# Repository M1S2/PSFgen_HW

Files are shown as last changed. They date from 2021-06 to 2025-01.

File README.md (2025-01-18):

# PS_Fgen_HW
Hardware for an PowerSupply and Functiongenerator build from an ATX power supply.

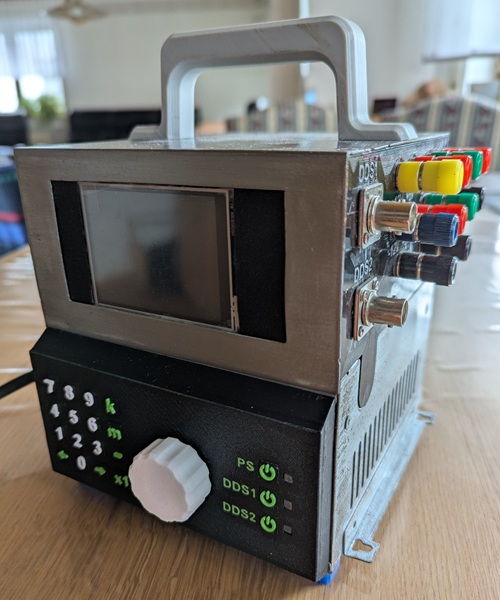
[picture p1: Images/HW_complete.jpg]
PS_Fgen_HW


## ATX Supply
The hardware of the power supply and function generator is based on the following ATX supply:
``Yuan Kee 230P ATX``

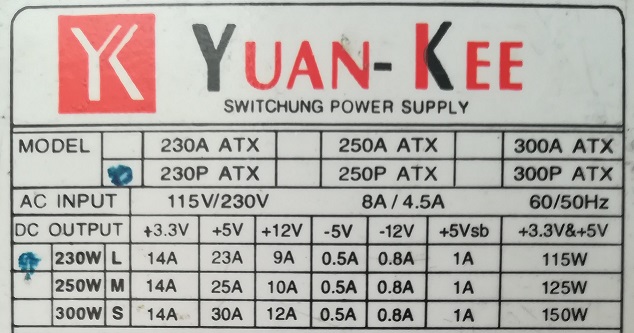
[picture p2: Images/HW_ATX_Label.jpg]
ATX


By using another ATX supply, some output capabilities can be changed / enhanced.

## Input / Output Capabilities

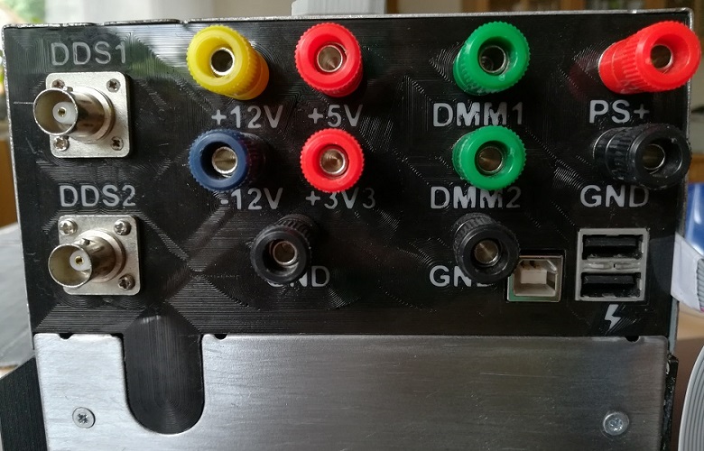
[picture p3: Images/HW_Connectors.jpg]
Connectors


The power supply and function generator features the following capabilites:

### Power Supply output (PS+)
One power supply output is available.
Connector		| PS+
-----------------------	| -----------------
Voltage			| 0 .. 10 V DC
Current			| 0 .. 2 A
Protections		| OVP, OCP, OPP

The voltage and current regulation is done in firmware.
The protections are implemented in firmware, too.

### DDS outputs (DDS1, DDS2)
Two direct digital synthesis outputs are available.
Connector		| DDS1						| DDS2
-----------------------	| ---------------------------------------------	| ---------------------------------------------
Amplitude		| 0 .. 20 Vpp					| 0 .. 20 Vpp
Offset			| -10 V .. 10 V					| -10 V .. 10 V
Frequency		| approx. max. 170 kHz				| approx. max. 170 kHz
Waveforms		| FW defined (Sine, Square, Triangle, ...)	| FW defined (Sine, Square, Triangle, ...)

The waveforms are defined in firmware. Default waveforms like sine, square and triangle are supported. By using DDS it is possible to even generate user defined waveforms.
The maximum frequency is limited by the low pass filter after the DAC outputs. The cutoff frequency is approximately 170 kHz. The real frequency range depends on the DDS implementation in the firmware!

### DMM inputs (DMM1, DMM2)
Two digital multimeter inputs are available.
Connector	| DMM1		| DMM2
---------------	| -------------	| ---------------
Input Range	| 0 .. 20 V DC	| 0 .. 20 V DC

Negative voltages on the DMM inputs between -20 V and 0 V are allowed but the output is clipped to 0 V!
The measured voltage for negative inputs is 0 V and a warning signal is generated.

### USB outputs
Two USB outputs are available. They are connected to the 5V output of the ATX supply. So the combined current capability for both USB ports are 23 A.

### USB input
The USB input can be used to communicate to the device via serial port.

### ATX outputs
All output voltages of the ATX supply are directly available through connectors on the connector panel. The currents are directly depending on the used ATX supply (values for the Yuan Kee 230P ATX).
Connector		| +5V	| +3V3	| +12V	| -12V
-----------------------	| -----	| -----	| -----	| -----
Voltage			| 5 V	| 3,3 V	| 12 V	| -12 V
Current (max.)		| 23 A	| 14 A	| 9 A	| 0.8 A

## User Interface

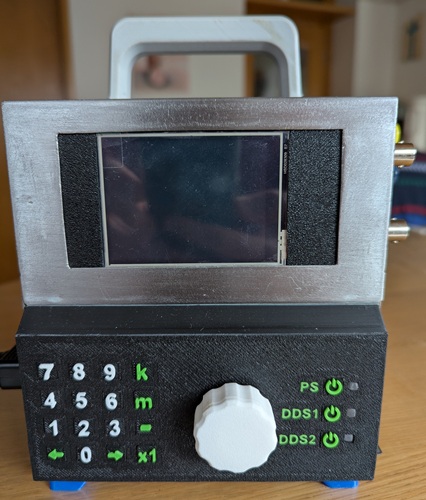
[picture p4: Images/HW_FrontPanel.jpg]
FrontPanel


The user interface is made up of the following components:
- Graphical display: A 320x240 pixel graphical LCD is used to display the device status and current settings.
- Encoder: A rotary encoder can be used for value editing and menu navigation.
- KeyPad: A 16 button keypad can be used for value editing and menu navigation.
- OnOffControls: A PCB with buttons and LEDs for faster enabling of the channels and status display.

The user interface logic is defined by the firmware.

## Electronic
The electronic is divided into the following PCBs:
- **FrontPanel:** The front panel is containing 16 push buttons forming a 4x4 keypad and a rotary encoder for user input. It is connected to the MainBoard using a ribbon cable.
- **MainBoard:** The main board is containing all other components that can be grouped like following:
	- *Microcontroller*: The main controller of the power supply and function generator. It controls everything from user input handling to output generation. The used type is an ATmega1284P.
	- *Serial communication:* A FT232RL USB-UART IC is used for serial communication to the microcontroller via USB.
	- *GLCD:* The used graphic LCD model is ``ILI9341``. It has 320x240 pixels and is controllable via SPI. **Important:** The display uses a 3.3 V logic level!
	- *ATX voltage monitors:* The ATX 5 V and 3.3 V lines are each directly connected to ADCs of the microcontroller. The 12V and -12V lines aren't monitored anymore because the input pins were needed for other purposes.
	- *DMM inputs:* The two DMM inputs can be used to measure positive input voltages. The resistor divider scales the input voltage so that the maximum DMM input voltage equals 5 V (maximum allowed voltage of the microcontroller ADC inputs).  **Important:** Voltages higher than the maximum DMM input voltage can damage the inputs.
	- *DDS outputs:* The two DDS output signals are generated by a dual output DAC IC (MCP4921, output 0..5 V for each output) followed by an offset and amplification stage (used to create a range of -10 V .. 10 V). The output is buffered by an OpAmp and two transistors for higher currents.
	- *PS output:* The PS output signal is generated by a single output DAC IC (MCP4921, output 0..5 V) and buffered by an OpAmp and two transistors for higher currents. The voltage at the PS output is measured by a simple resistor voltage divider. The current at the PS output is measured by transforming it into a voltage proportional to the current.
- **DMMRectifier:** The DMMRectifier is used to protect the ADC DMM inputs from negative inputs on the DMM1 and DMM2 connectors. Negative voltages are clipped to 0 V and a warning signal is generated when the voltage on the inputs are negative.
- **OnOffControls:** The OnOffControls are buttons and LEDs for faster enabling of the channels and status display.

The FrontPanel, DMMRectifier and OnOffControls PCBs were designed to be manufactured with toner transfer method.

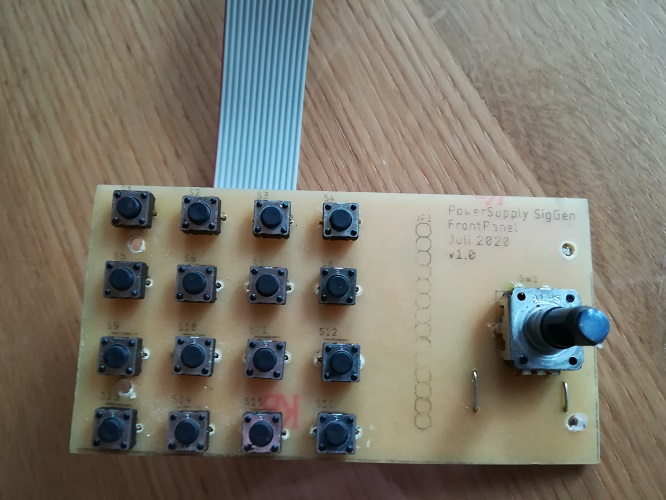
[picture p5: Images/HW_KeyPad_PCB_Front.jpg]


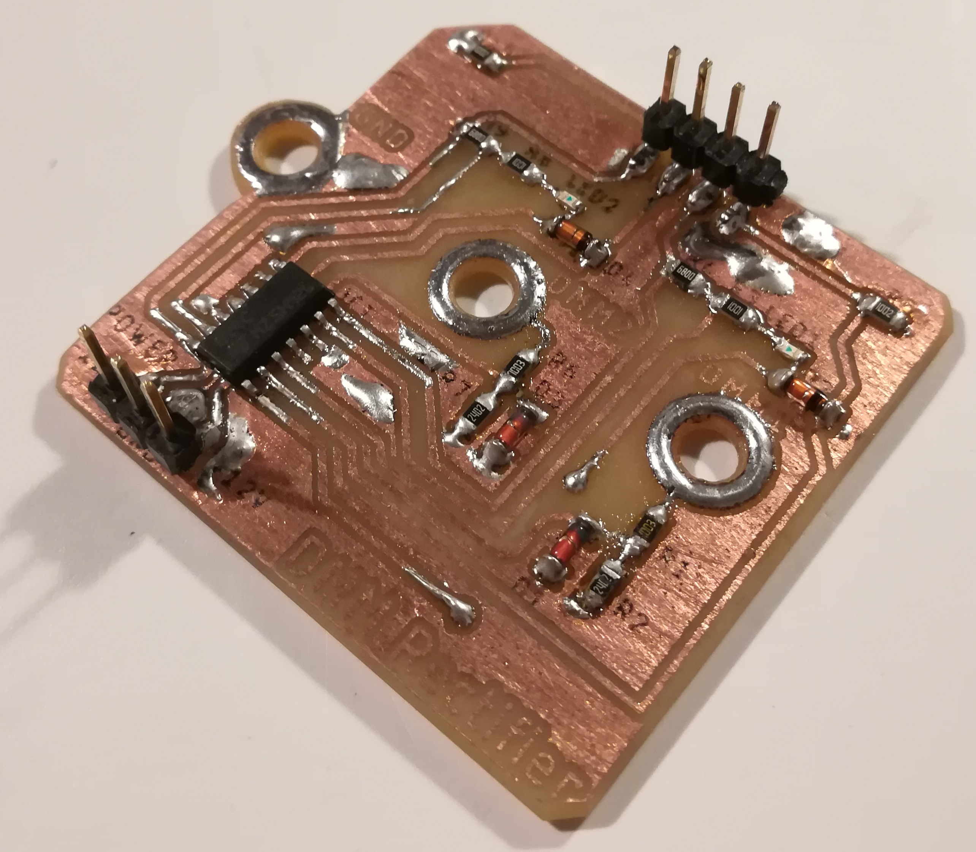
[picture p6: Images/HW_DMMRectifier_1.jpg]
DMMRectifier


The MainBoard PCB was too complex for manual manufacturing and was therefore made by JLCPCB.

!!! :warning: Caution: The MainBoard was designed to a size of 100 x 100 mm to fit the maximum size of JLCPCB. Eagle changed the maximum board size to 100 x 80 mm in 2022. Therefore the board can't be modified anymore. But the schematics are up-to-date. !!! 

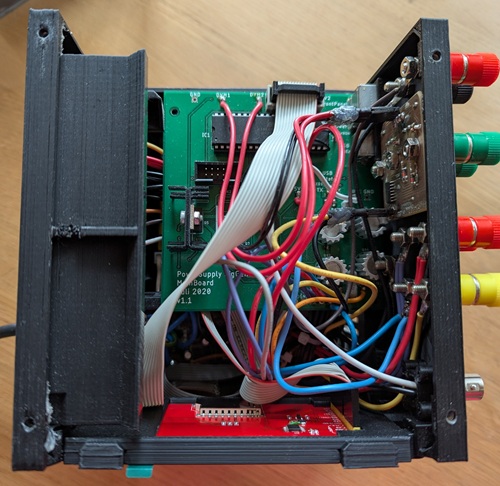
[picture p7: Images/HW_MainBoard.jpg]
MainBoard


## Housing
All housing components are made for the above ATX supply and are not guaranteed to fit for any other ATX supply. Nevertheless all construction files are available in the Mechanical folder and can be adapted, if neccessary.
The parts were designed using Autodesk Fusion 360 (.f3d files) and are exported as .stl files.
The .stl files were used to 3D print all components.
All parts are needed once, except the `Standfuss.stl` (needed 4x).

## Firmware
The firmware for this power supply and function generator is developed in another repository:
[GitHub - M1S2/PS_Fgen_FW: Firmware for an Power Supply and Function Generator build from an ATX power supply](https://github.com/M1S2/PS_Fgen_FW)

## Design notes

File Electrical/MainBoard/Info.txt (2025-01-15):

No gerber or other output files because the PCB isn't really up to date (and it won't be anymore).
This is because of the new limitations of Fusion360 to a board size of 80x80 (previous was 100x100). The board must be completely redesigned.

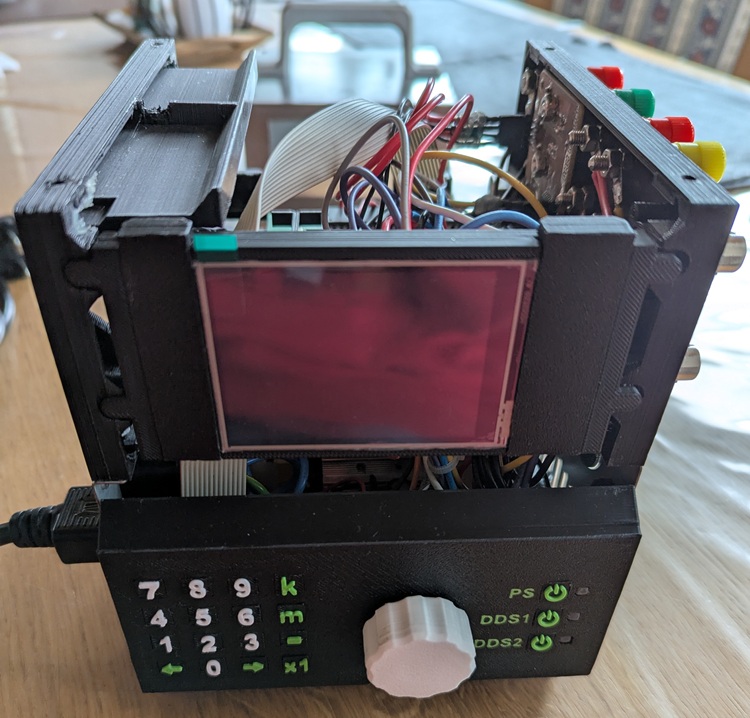
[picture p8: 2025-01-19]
Images/HW_WithoutCover.jpg

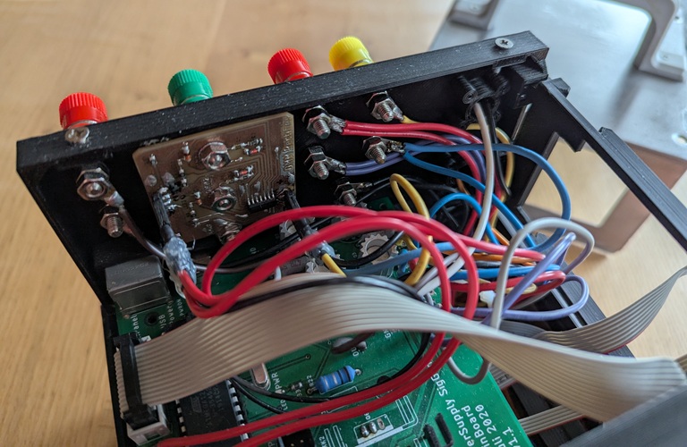
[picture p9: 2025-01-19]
Images/HW_Connectors_connection.jpg

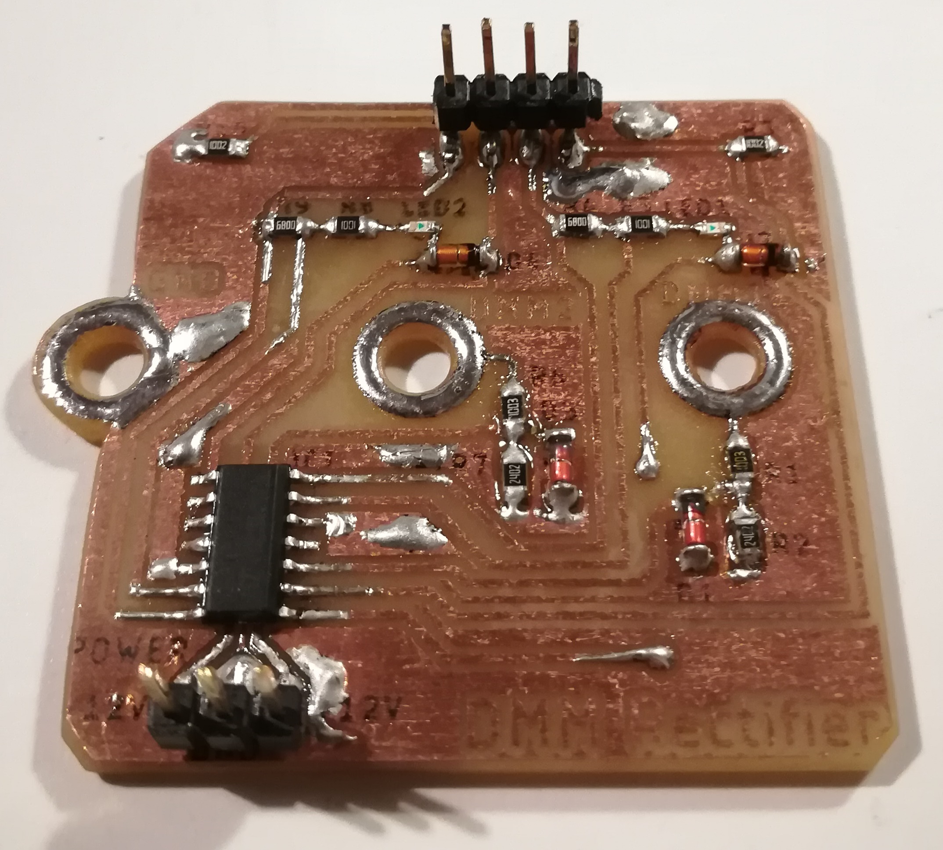
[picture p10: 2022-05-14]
Images/HW_DMMRectifier_3.jpg

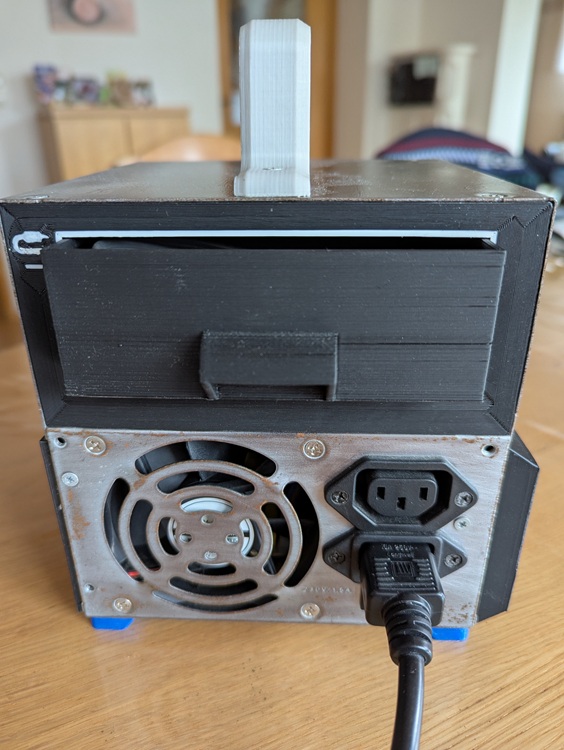
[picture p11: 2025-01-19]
Images/HW_Side.jpg

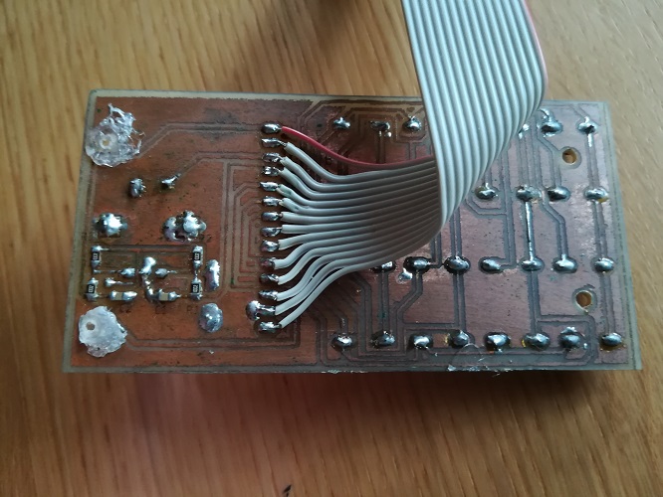
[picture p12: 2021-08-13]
Images/HW_KeyPad_PCB_Back.jpg

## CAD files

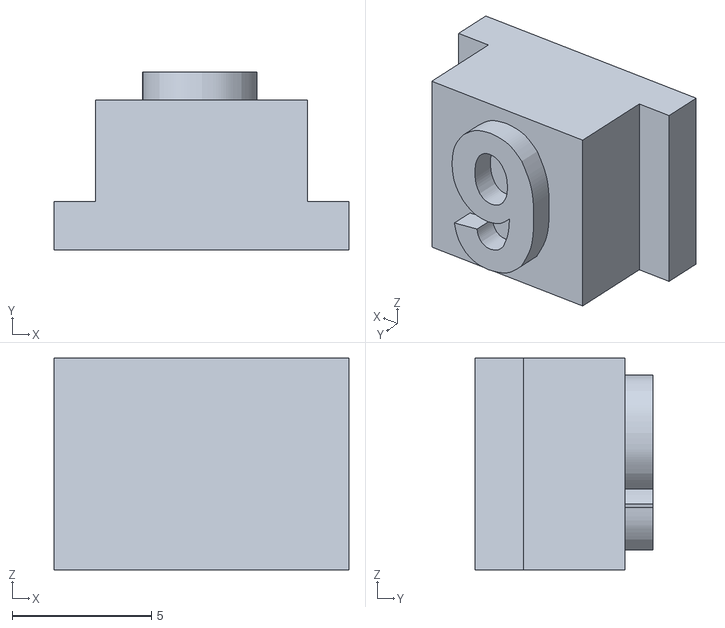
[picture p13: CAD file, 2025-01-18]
Mechanical/Taste9_v56.stl
10.6 x 6.40 x 7.60

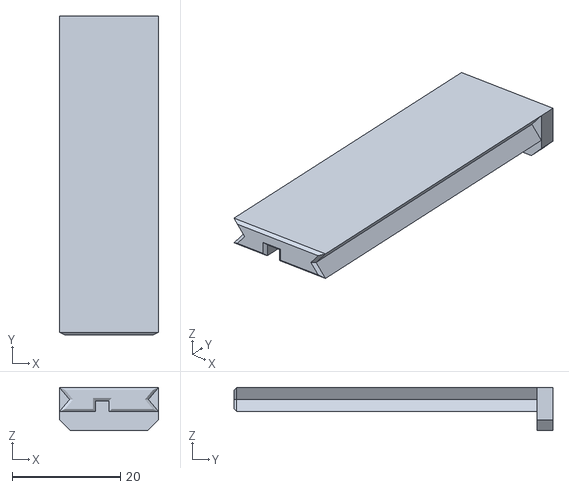
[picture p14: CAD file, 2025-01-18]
Mechanical/TFT_Holder_2_v4.stl
18.4 x 59.0 x 8.00

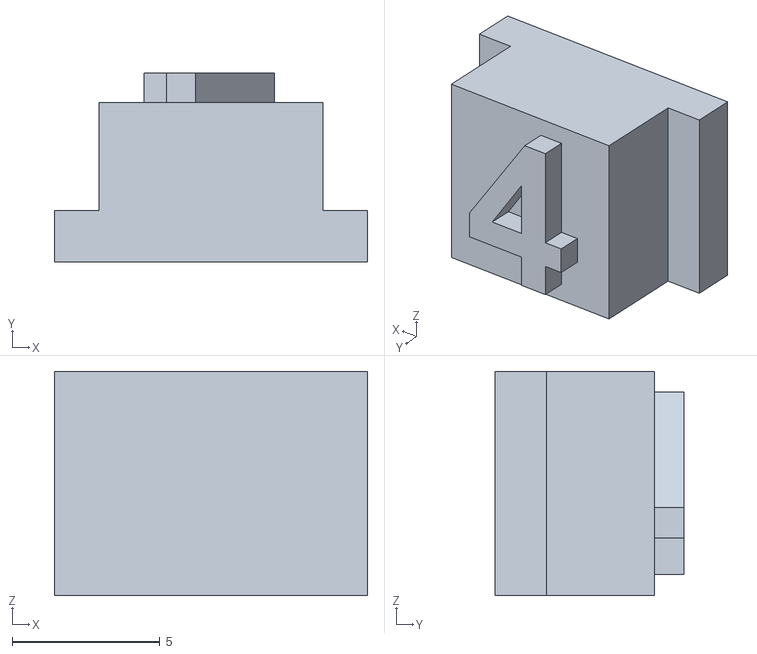
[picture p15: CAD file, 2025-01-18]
Mechanical/Taste4_v56.stl
10.6 x 6.40 x 7.60

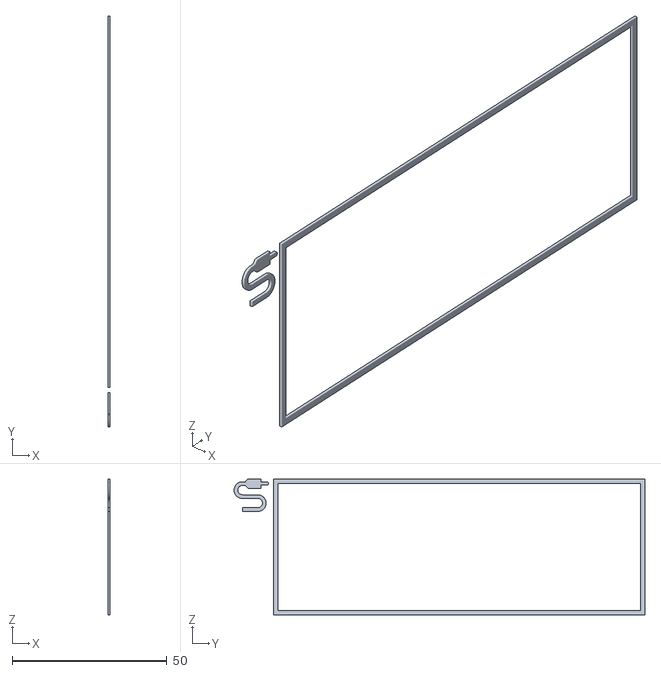
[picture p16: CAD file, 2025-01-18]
Mechanical/Schrift_Seitenteil_links_v56.stl
0.6 x 133.0 x 44.0

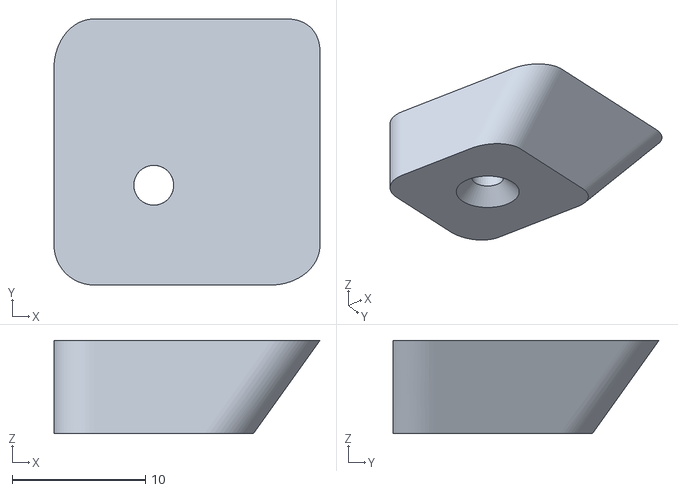
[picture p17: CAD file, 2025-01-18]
Mechanical/Standfuss_v56.stl
20.0 x 20.0 x 7.00

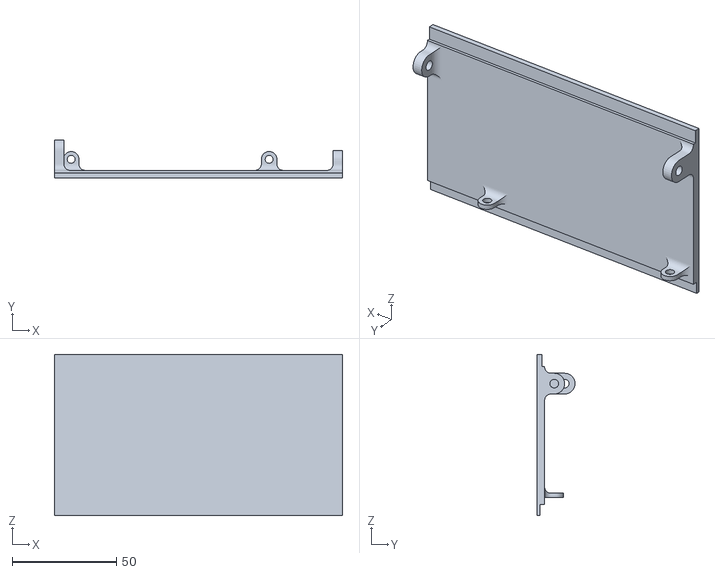
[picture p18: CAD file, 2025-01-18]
Mechanical/Abdeckung_hinten_v56.stl
138.2 x 18.3 x 77.3

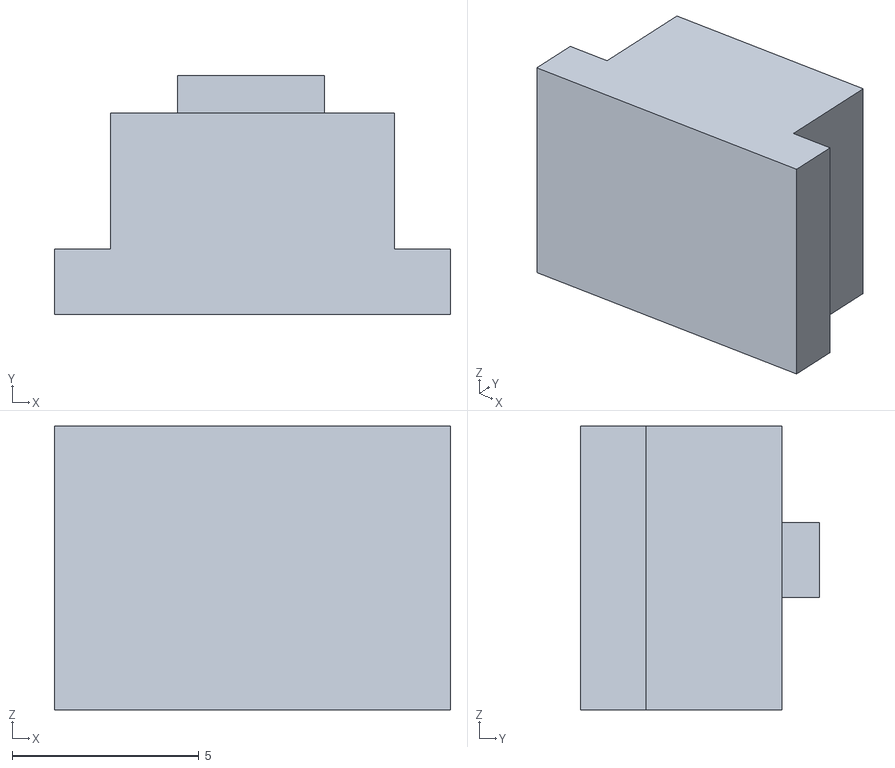
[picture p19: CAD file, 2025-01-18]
Mechanical/Taste_minus_v56.stl
10.6 x 6.40 x 7.60

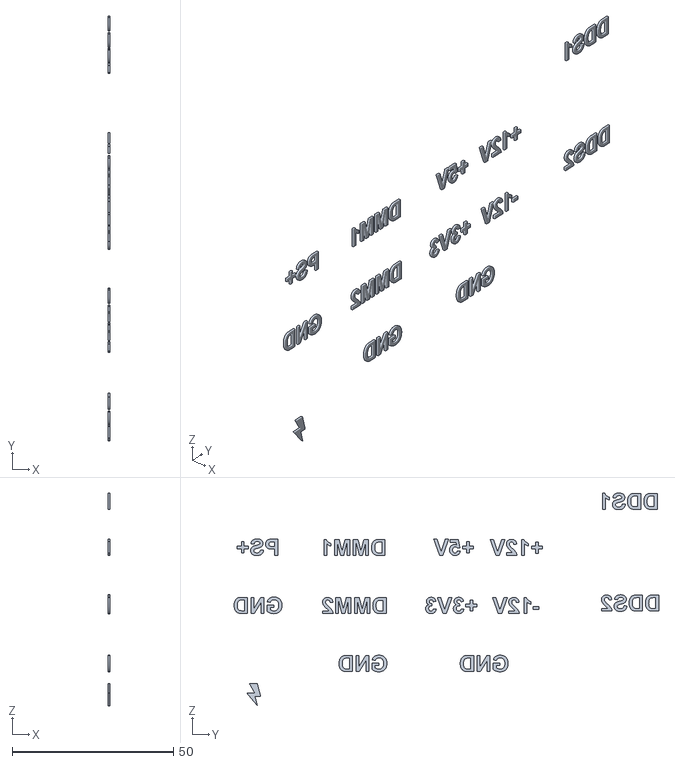
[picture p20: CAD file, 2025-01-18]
Mechanical/Schrift_Seitenteil_rechts_v56.stl
0.5 x 131.6 x 66.0

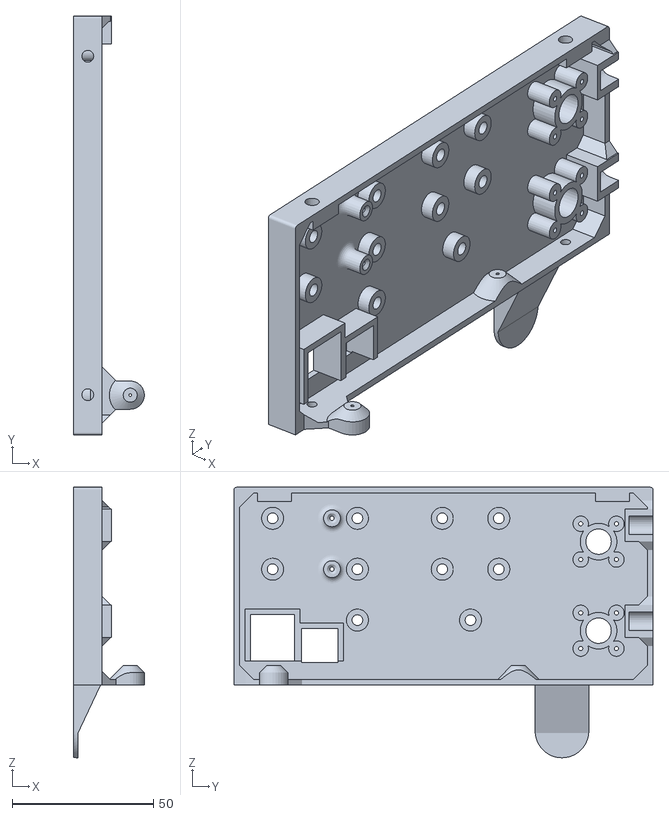
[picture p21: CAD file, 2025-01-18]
Mechanical/Seitenteil_rechts_v56.stl
25.0 x 148.2 x 95.7

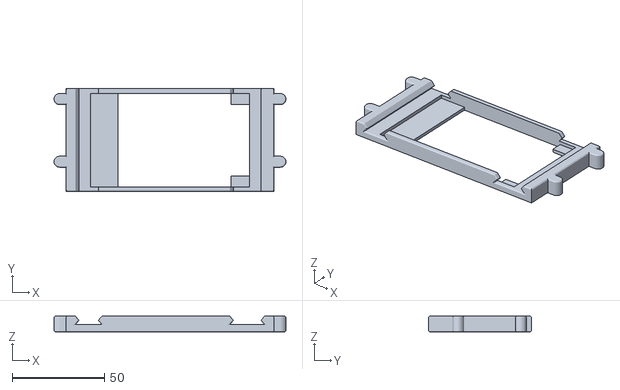
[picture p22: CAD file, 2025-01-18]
Mechanical/TFT_Adapter_v4.stl
125.9 x 56.0 x 8.44

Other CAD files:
Mechanical/Taste8_v56.stl
Mechanical/Taste_x1_v56.stl
Mechanical/Taste2_v56.stl
Mechanical/Taste5_v56.stl
Mechanical/Taste_links_v56.stl
Mechanical/Taste_k_v56.stl
Mechanical/Taste_rechts_v56.stl
Mechanical/Taste7_v56.stl
Mechanical/Abdeckung_hinten_v56.f3d
Mechanical/Encoder_Knopf_v56.f3d
Mechanical/Encoder_Knopf_v56.stl
Mechanical/FrontPanel_Rahmen_Schrift_v56.stl
Mechanical/FrontPanel_Rahmen_v56.f3d
Mechanical/FrontPanel_Rahmen_v56.stl
Mechanical/Griff_v56.f3d
Mechanical/Griff_v56.stl
Mechanical/Schrift_Seitenteil_links_v56.f3d
Mechanical/Schrift_Seitenteil_rechts_v56.f3d
Mechanical/Seitenteil_links_Schublade_v56.f3d
Mechanical/Seitenteil_links_Schublade_v56.stl
Mechanical/Seitenteil_links_v56.f3d
Mechanical/Seitenteil_links_v56.stl
Mechanical/Seitenteil_rechts_v56.f3d
Mechanical/Standfuss_v56.f3d
Mechanical/TFT_Holder_1_v4.stl
Mechanical/Taste0_v56.f3d
Mechanical/Taste0_v56.stl
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

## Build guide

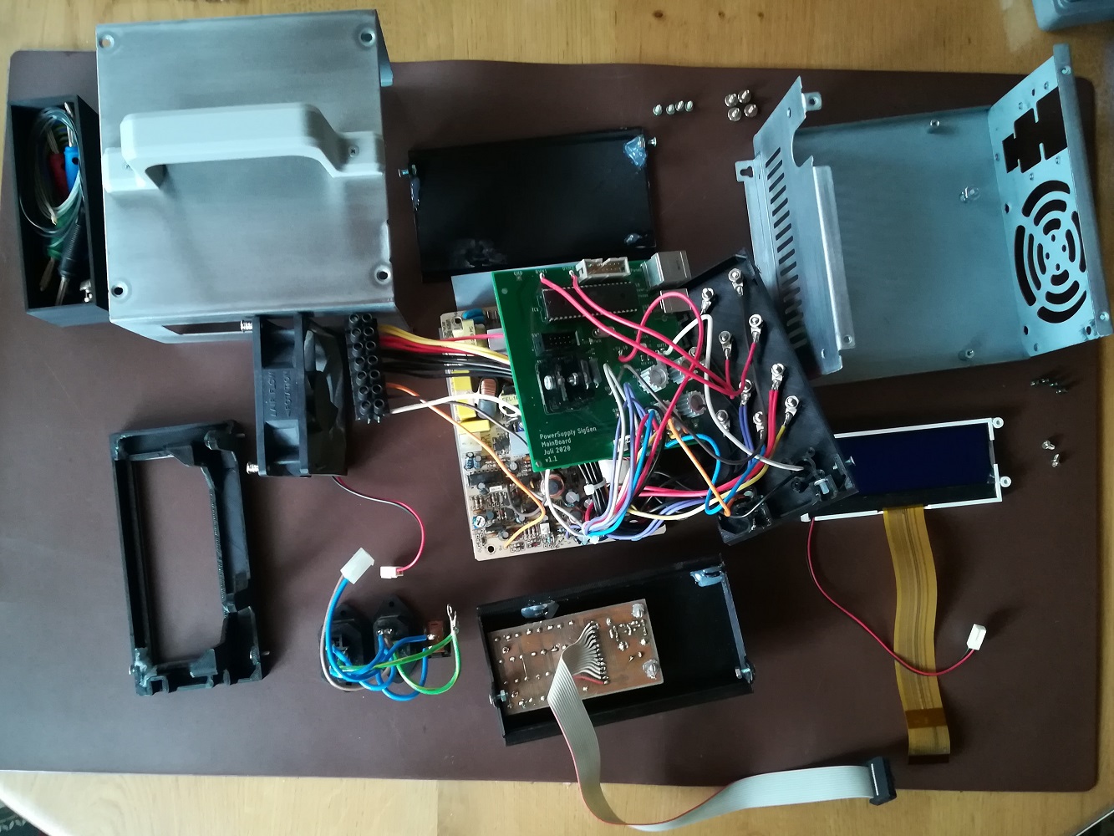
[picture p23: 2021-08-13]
Images/HW_Assembly1.jpg

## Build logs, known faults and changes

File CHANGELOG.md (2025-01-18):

# PS_Fgen_HW

## [%version%] - %date%

> Electrical > FrontPanel
- Nothing changed (equal to v1.1)
- Updated to new project name (PS_Fgen_HW)

> Electrical > MainBoard
- Resistors added to convert 5V to 3.3V for LCD signals (A0, CS, MOSI, SCK)
- Updated to new project name (PS_Fgen_HW)
- Removed some Z-Diodes
- Removed ATX_PWR_ON signal
- Removed ATX_5V_SB input (combined VCC and +5V nets)
- Removed resistor R20 (PowerSupply, between OpAmp IC5B and transistors Q5 and Q6)
- Changed resistor values of PowerSupply current measurement circuit (R21, R22, R23)
- Moved resistor R21 of current measurement circuit to be after this circuit
- Changed power stage of PowerSupply channel
- Modified DMM circuit to use DMMRectifier PCB
- ...

> Electrical > DMMRectifier
- Initial version of DMM Rectifier with simulation

> Mechanical
- Added Standfuss parts
- Modified Seitenteil_rechts for DMMRectifier
- ...

## [v1.1] - 07.08.2020
> Electrical > FrontPanel
- Nothing changed (equal to v1.0)

> Electrical > MainBoard
- Board size decreased to 100x100 to fit JLCPCB requirements for cheapter price
- Schematic not changed

> Mechanical
- Nothing changed (equal to v1.0)

## [v1.0] - 05.08.2020
> Electrical > FrontPanel
- Initial version

> Electrical > MainBoard
- Initial version

> Mechanical
- Initial version

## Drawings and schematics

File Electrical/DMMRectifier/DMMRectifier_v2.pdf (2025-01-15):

A

A

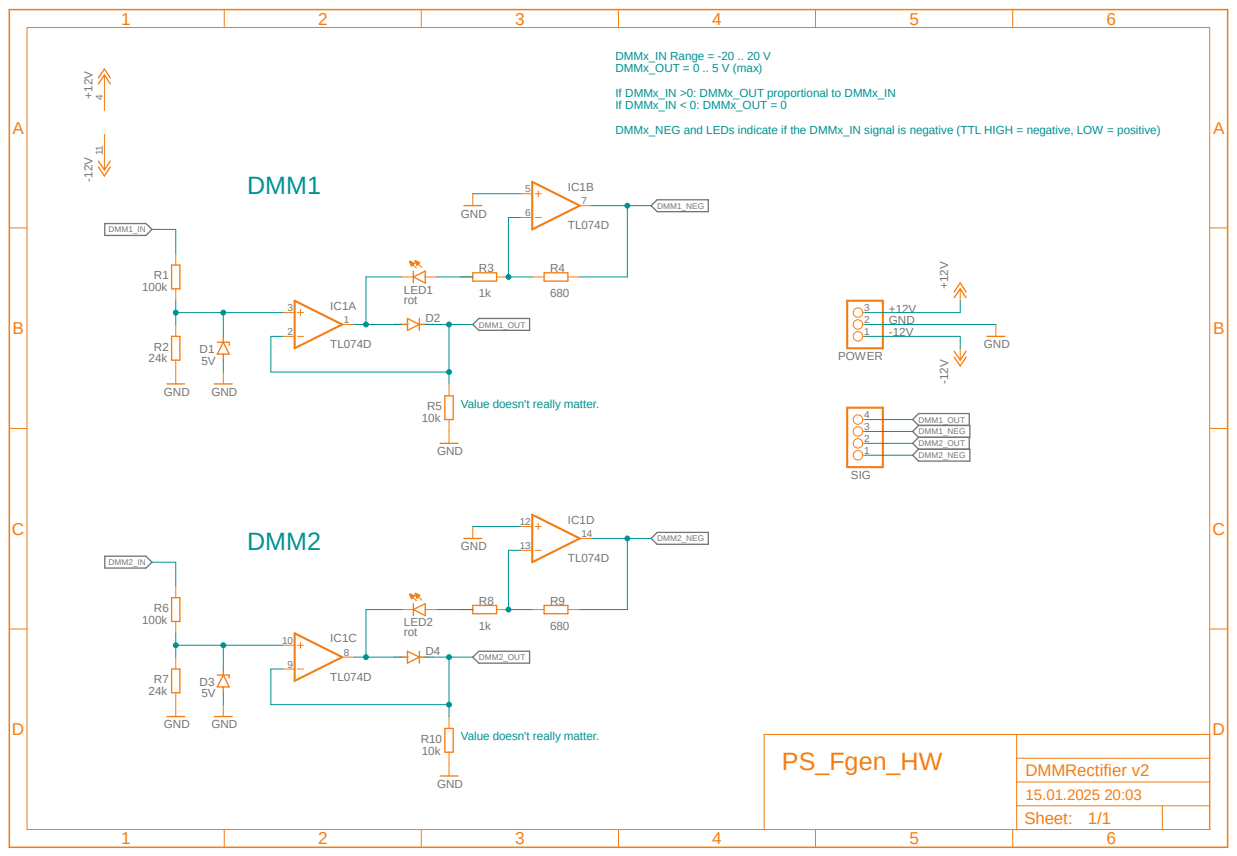
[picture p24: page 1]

DMMx_IN Range = -20 .. 20 V
DMMx_OUT = 0 .. 5 V (max)
If DMMx_IN >0: DMMx_OUT proportional to DMMx_IN
If DMMx_IN < 0: DMMx_OUT = 0
DMMx_NEG and LEDs indicate if the DMMx_IN signal is negative (TTL HIGH = negative, LOW = positive)

Value doesn't really matter.

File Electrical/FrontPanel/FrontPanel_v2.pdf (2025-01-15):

# Encoder +5V

# KEY_C1 KEY_C²

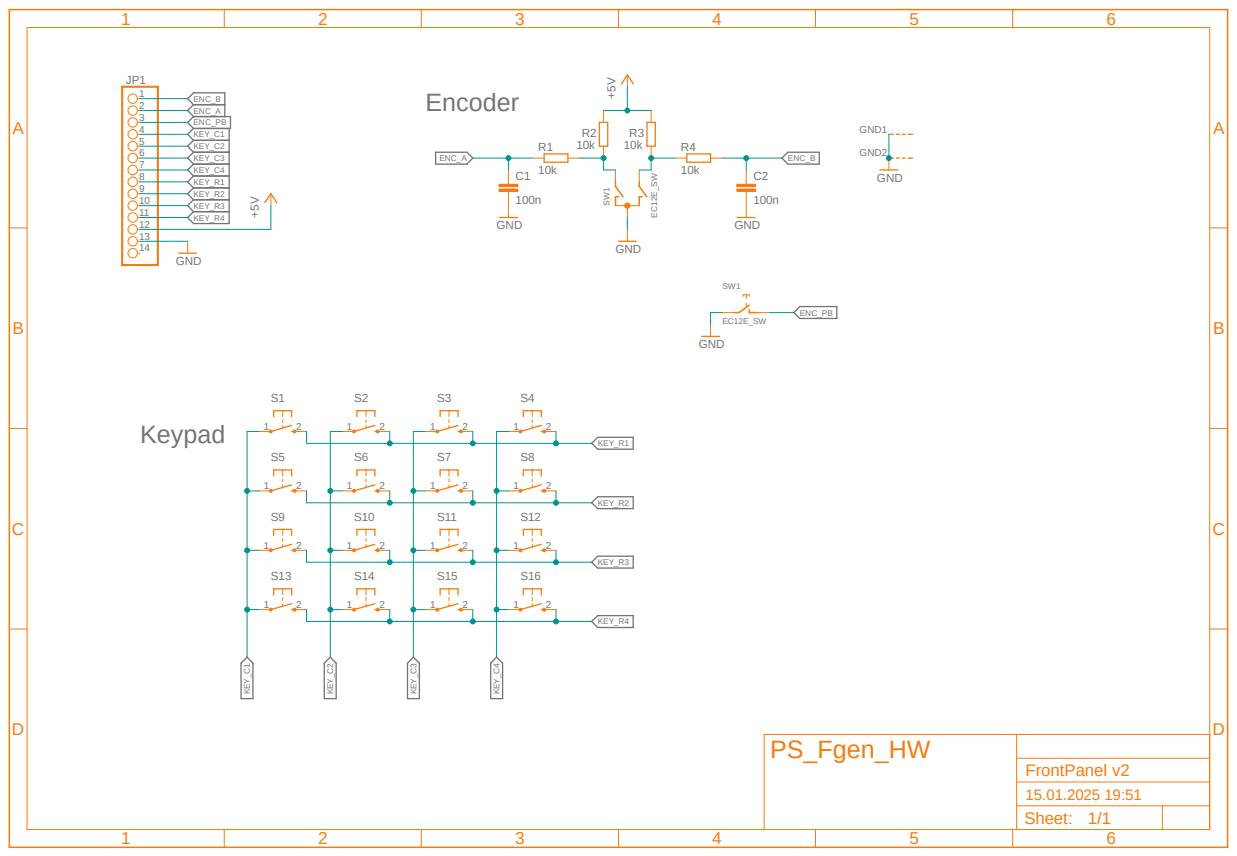
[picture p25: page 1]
Keypad; GND; EC¹²E_SW; GND ⁺⁵VJP1 1 2 3 4 5 6 7 8 9 10 11 12 13; 14 SW¹; GND1; GND2; C2 KEY_C¹; KEY_C2; KEY_C³; KEY_C3; KEY_C⁴; KEY_C4; KEY_R1; KEY_R2; KEY_R3; KEY_R4; ENC_PB; ENC_B; ENC_A; FrontPanel v2

PS_Fgen_HW

Sheet: 1/1

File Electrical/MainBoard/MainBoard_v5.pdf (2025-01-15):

A

A

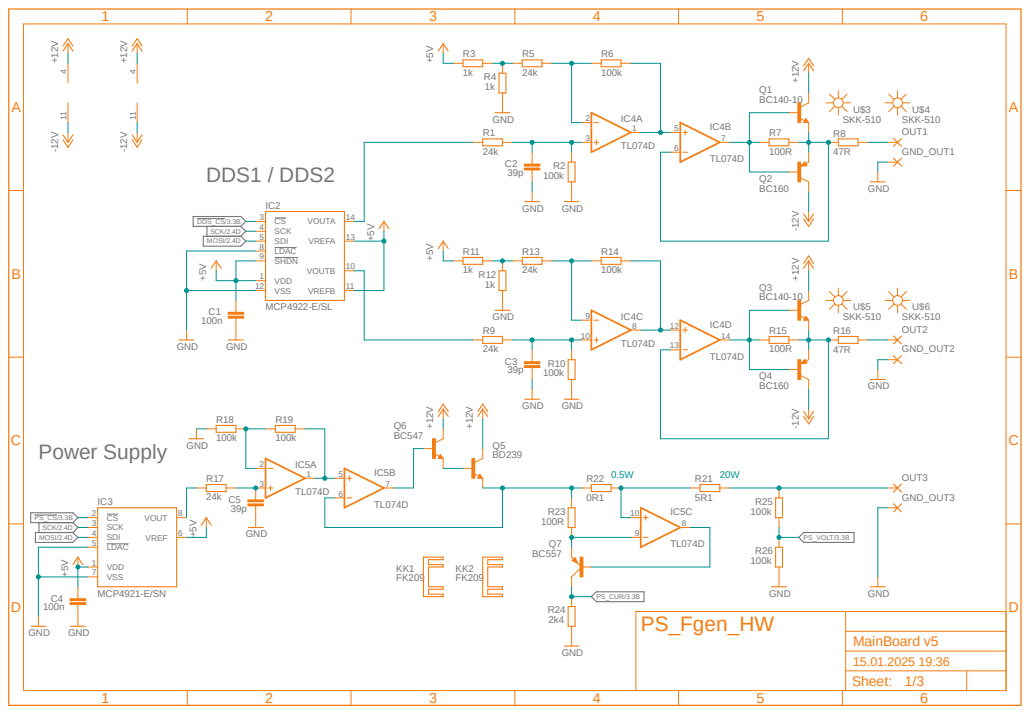
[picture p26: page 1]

PS_Fgen_HW

Sheet: 1/3

# Display / Touch

# USB Power ATX Power Input

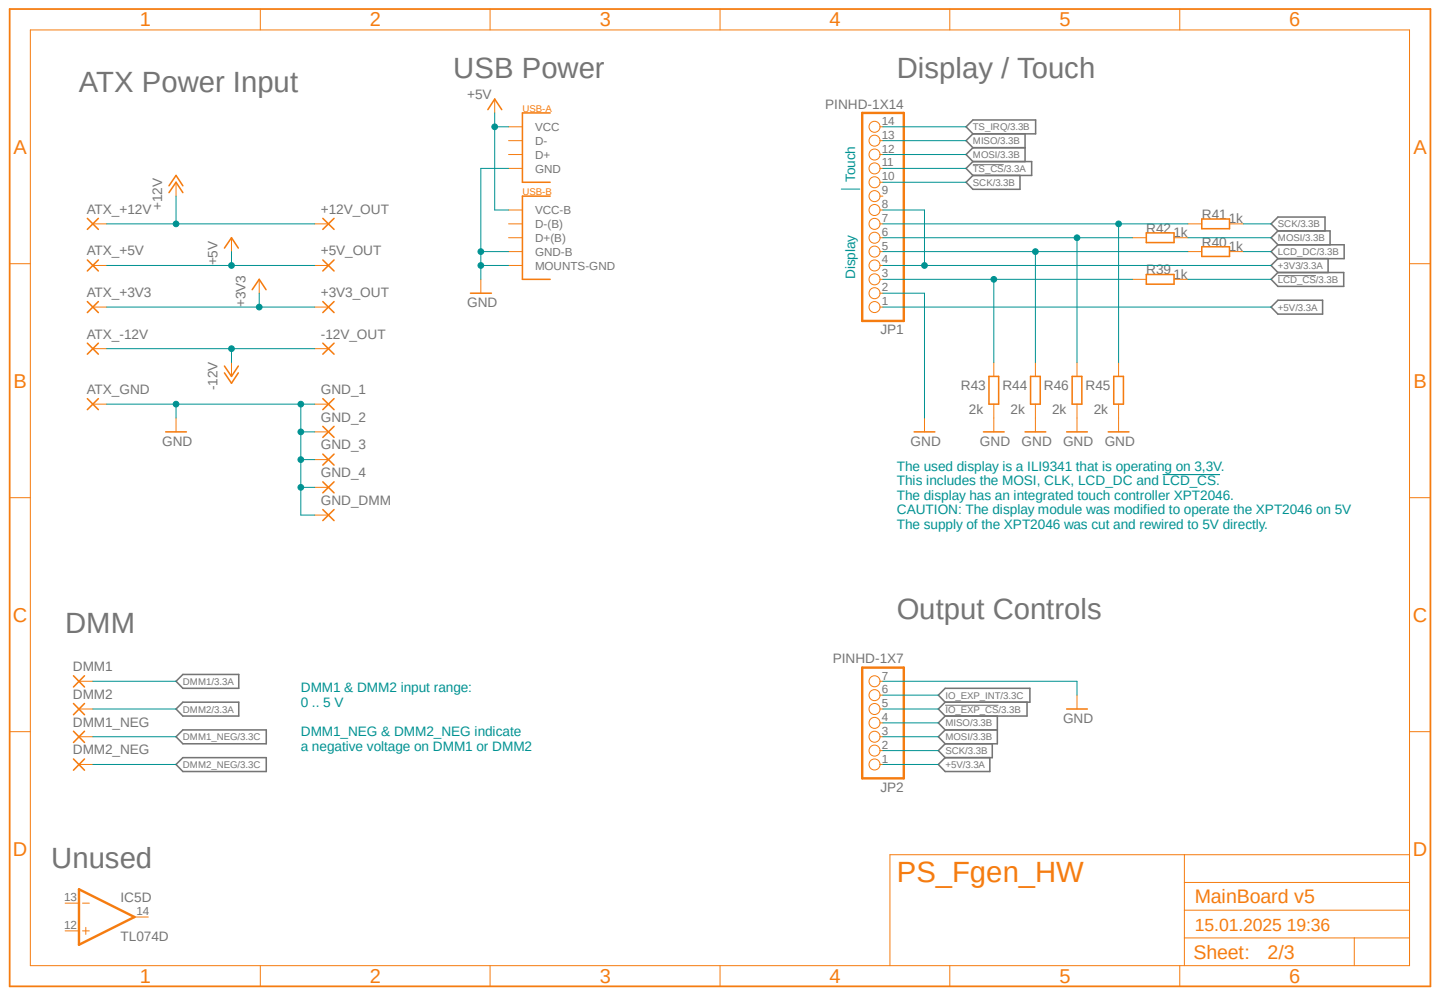
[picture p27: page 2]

The supply of the XPT2046 was cut and rewired to 5V directly. Display Touch

GND
The used display is a ILI9341 that is operating on 3,3V.
This includes the MOSI, CLK, LCD_DC and LCD_CS.
The display has an integrated touch controller XPT2046.
CAUTION: The display module was modified to operate the XPT2046 on 5V

PS_Fgen_HW

Sheet: 2/3

Microcontroller | ISP
GND 11 | RESET 9

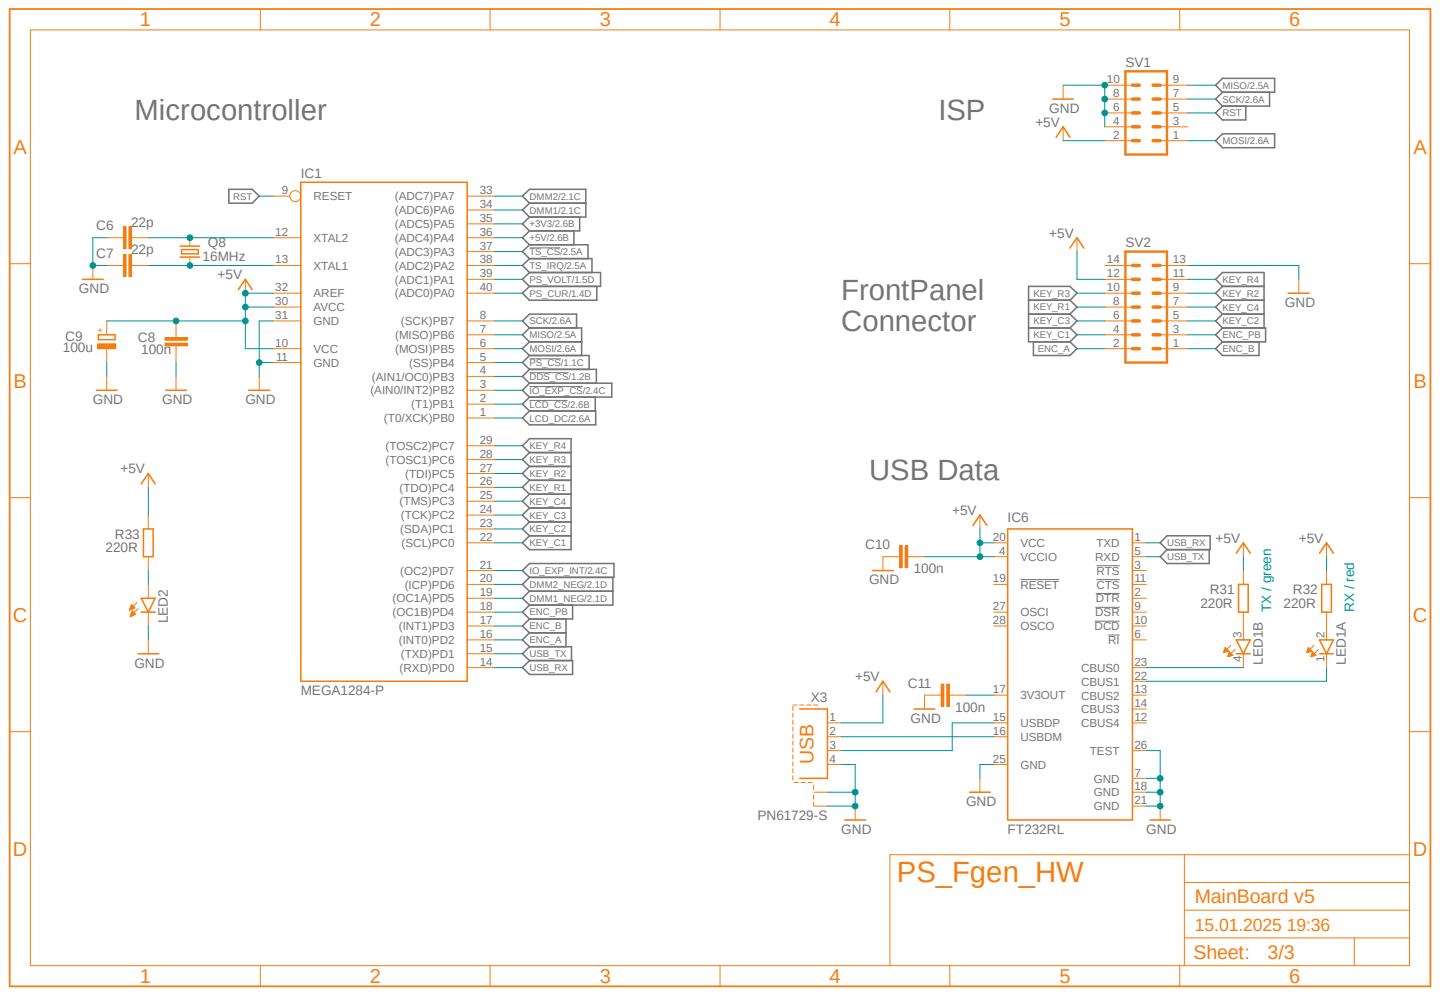
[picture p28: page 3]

PS_Fgen_HW

Sheet: 3/3

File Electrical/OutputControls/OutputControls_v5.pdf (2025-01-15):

A

A

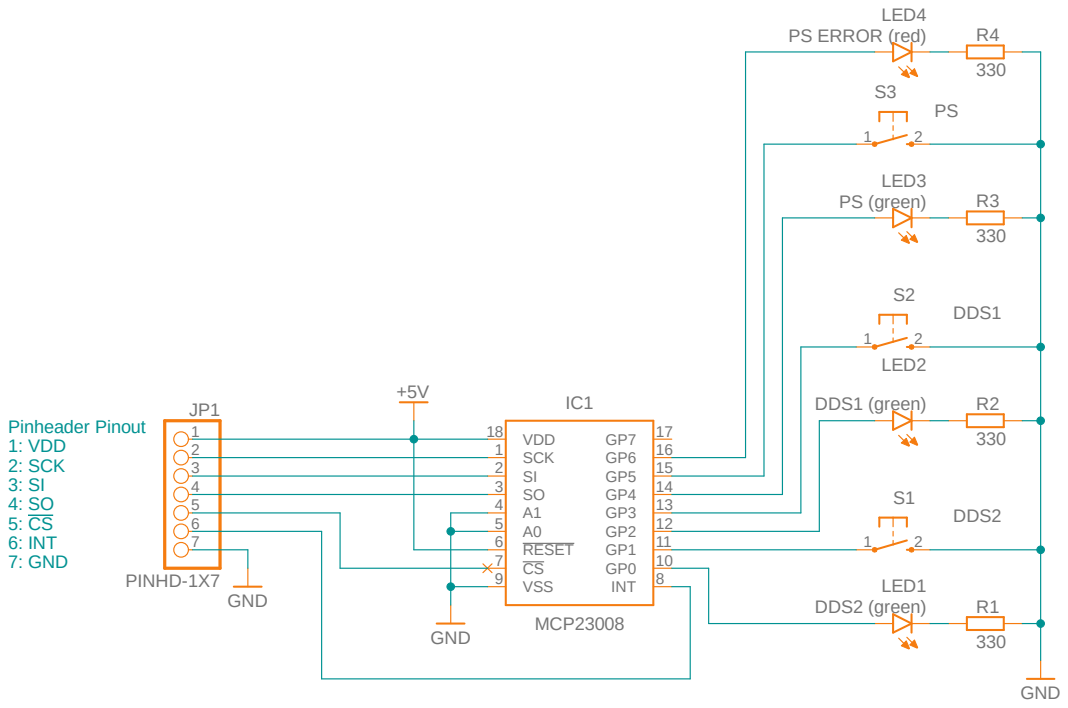
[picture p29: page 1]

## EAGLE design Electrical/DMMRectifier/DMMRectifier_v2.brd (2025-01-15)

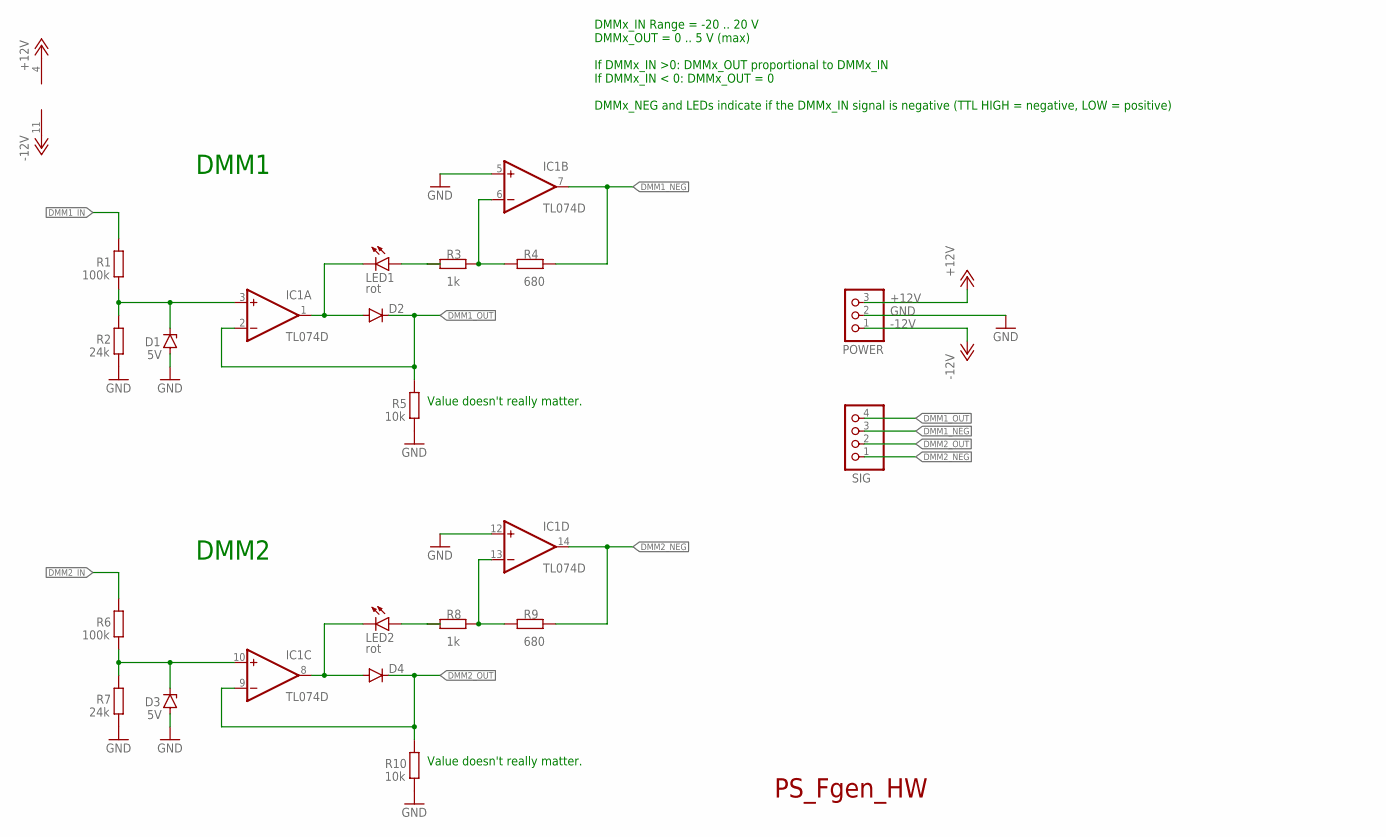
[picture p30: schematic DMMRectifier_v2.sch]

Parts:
D1, D3: 5V; SOD80C
D2, D4: DIODE-SOD80C; SOD80C
IC1: TL074D; SO14
LED1, LED2: rot; CHIPLED_0603
POWER: PINHD-1X3; 1X03
R1, R6: 100k; R0805
R2, R7: 24k; R0805
R3, R8: 1k; R0805
R4, R9: 680; R0805
R5, R10: 10k; R0805
SIG: PINHD-1X4; 1X04

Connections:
+12V: IC1.4 (V+), POWER.3
-12V: IC1.11 (V-), POWER.1
DMM1_IN: R1.2
DMM1_NEG: IC1.7 (OUT), R4.1, SIG.3
DMM1_OUT: D2.C, IC1.2 (-IN), R5.2, SIG.4
DMM2_IN: R6.2
DMM2_NEG: IC1.14 (OUT), R9.1, SIG.1
DMM2_OUT: D4.C, IC1.9 (-IN), R10.2, SIG.2
GND: D1.A, D3.A, IC1.5 (+IN), IC1.12 (+IN), POWER.2, R2.1, R5.1, R7.1, R10.1
unnamed: D1.C, IC1.3 (+IN), R1.1, R2.2
unnamed: D3.C, IC1.10 (+IN), R6.1, R7.2
unnamed: IC1.6 (-IN), R3.1, R4.2
unnamed: D2.A, IC1.1 (OUT), LED1.C
unnamed: LED1.A, R3.2
unnamed: IC1.13 (-IN), R8.1, R9.2
unnamed: D4.A, IC1.8 (OUT), LED2.C
unnamed: LED2.A, R8.2

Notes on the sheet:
PS_Fgen_HW
DMMx_IN Range = -20 .. 20 V DMMx_OUT = 0 .. 5 V (max) If DMMx_IN >0: DMMx_OUT proportional to DMMx_IN If DMMx_IN < 0: DMMx_OUT = 0 DMMx_NEG and LEDs indicate if the DMMx_IN signal is negative (TTL HIGH = negative, LOW = positive)
DMM1
DMM2
Value doesn't really matter.

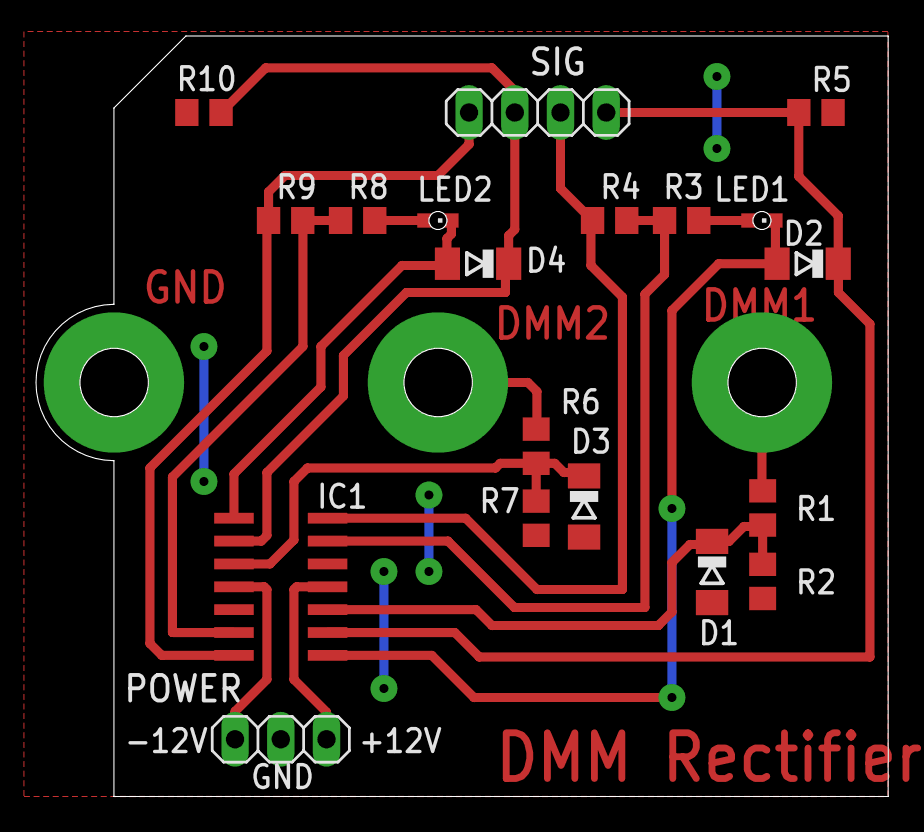
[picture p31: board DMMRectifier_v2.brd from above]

Board: 2 copper layers, 47.3 x 42.2 mm, 19 parts (0 on the bottom side), 15 nets.

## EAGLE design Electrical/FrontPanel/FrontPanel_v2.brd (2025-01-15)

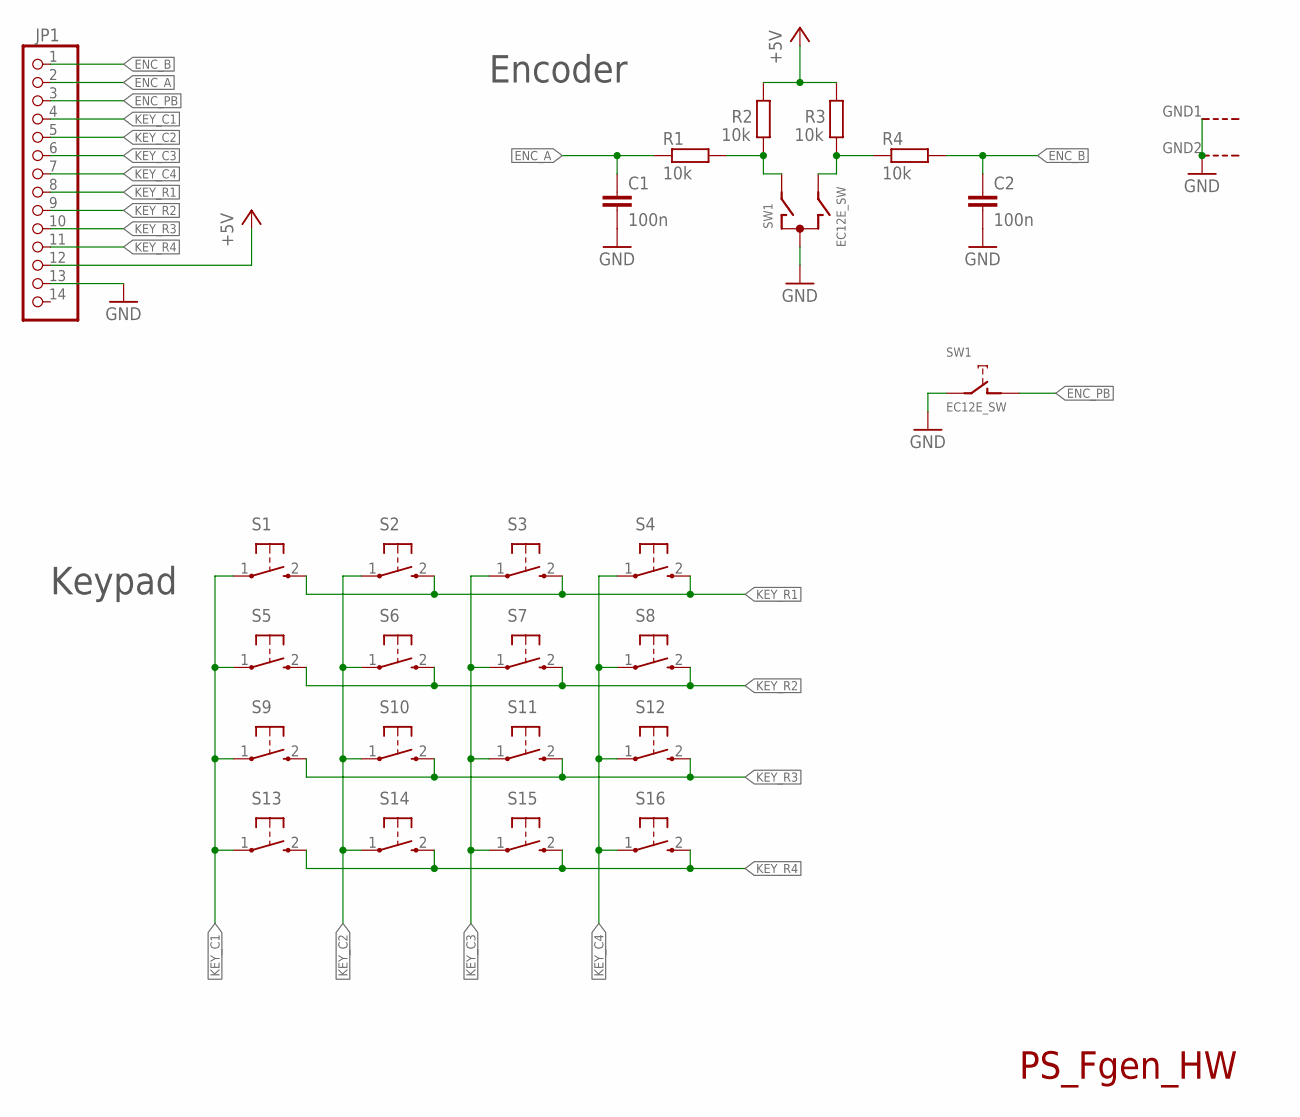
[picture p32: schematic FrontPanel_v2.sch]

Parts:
C1, C2: 100n; C0805
JP1: PINHD-1X14; 1X14
R1, R2, R3, R4: 10k; R0805
S1, S2, S3, S4, S5, S6, S7, S8, S9, S10, S11, S12, S13, S14, S15, S16: KURZHUBTASTER; B3F-10XX
SW1: EC12E_SW; ALPS_EC12E_SW

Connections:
+5V: JP1.12, R2.2, R3.2
ENC_A: C1.1, JP1.2, R1.1
ENC_B: C2.1, JP1.1, R4.2
ENC_PB: JP1.3, SW1.D (1)
GND: C1.2, C2.2, JP1.13, SW1.C, SW1.E (2), SW1.GND1 (G), SW1.GND2 (G)
KEY_C1: JP1.4, S1.1, S5.1, S9.1, S13.1
KEY_C2: JP1.5, S2.1, S6.1, S10.1, S14.1
KEY_C3: JP1.6, S3.1, S7.1, S11.1, S15.1
KEY_C4: JP1.7, S4.1, S8.1, S12.1, S16.1
KEY_R1: JP1.8, S1.2 (S), S2.2 (S), S3.2 (S), S4.2 (S)
KEY_R2: JP1.9, S5.2 (S), S6.2 (S), S7.2 (S), S8.2 (S)
KEY_R3: JP1.10, S9.2 (S), S10.2 (S), S11.2 (S), S12.2 (S)
KEY_R4: JP1.11, S13.2 (S), S14.2 (S), S15.2 (S), S16.2 (S)
unnamed: R1.2, R2.1, SW1.A
unnamed: R3.1, R4.1, SW1.B

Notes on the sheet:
PS_Fgen_HW
Keypad
Encoder

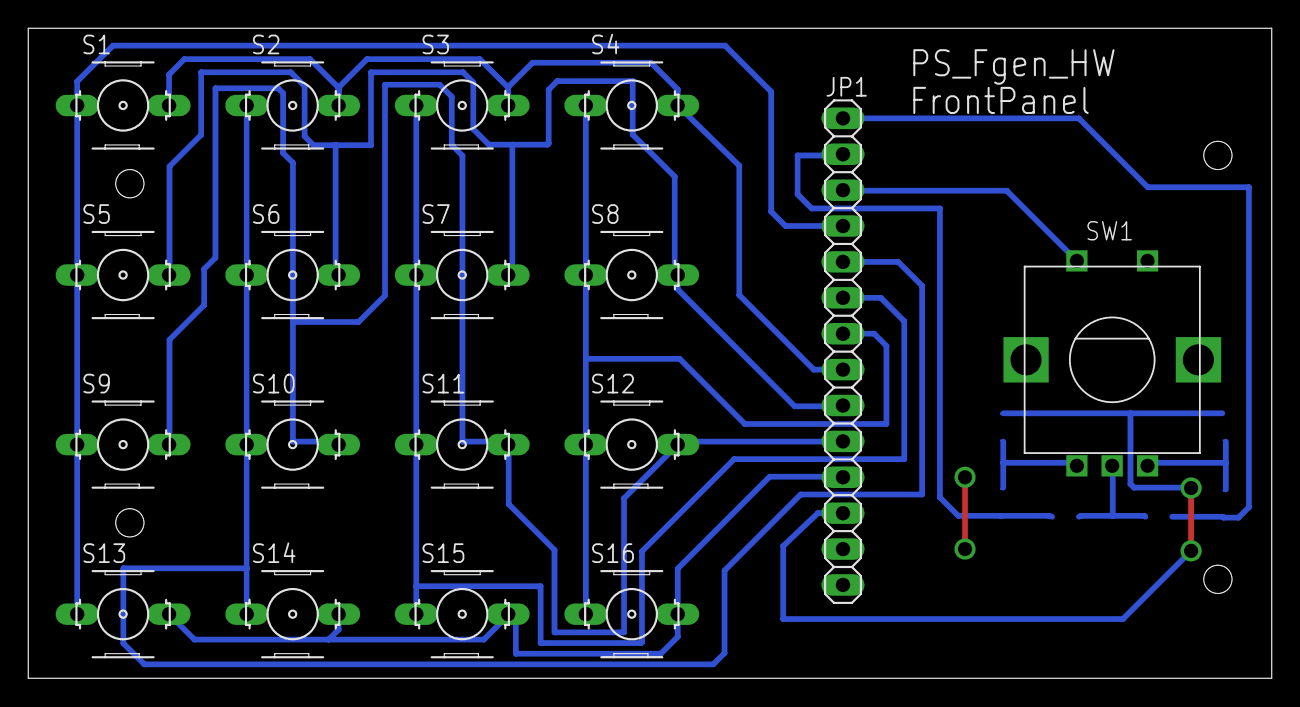
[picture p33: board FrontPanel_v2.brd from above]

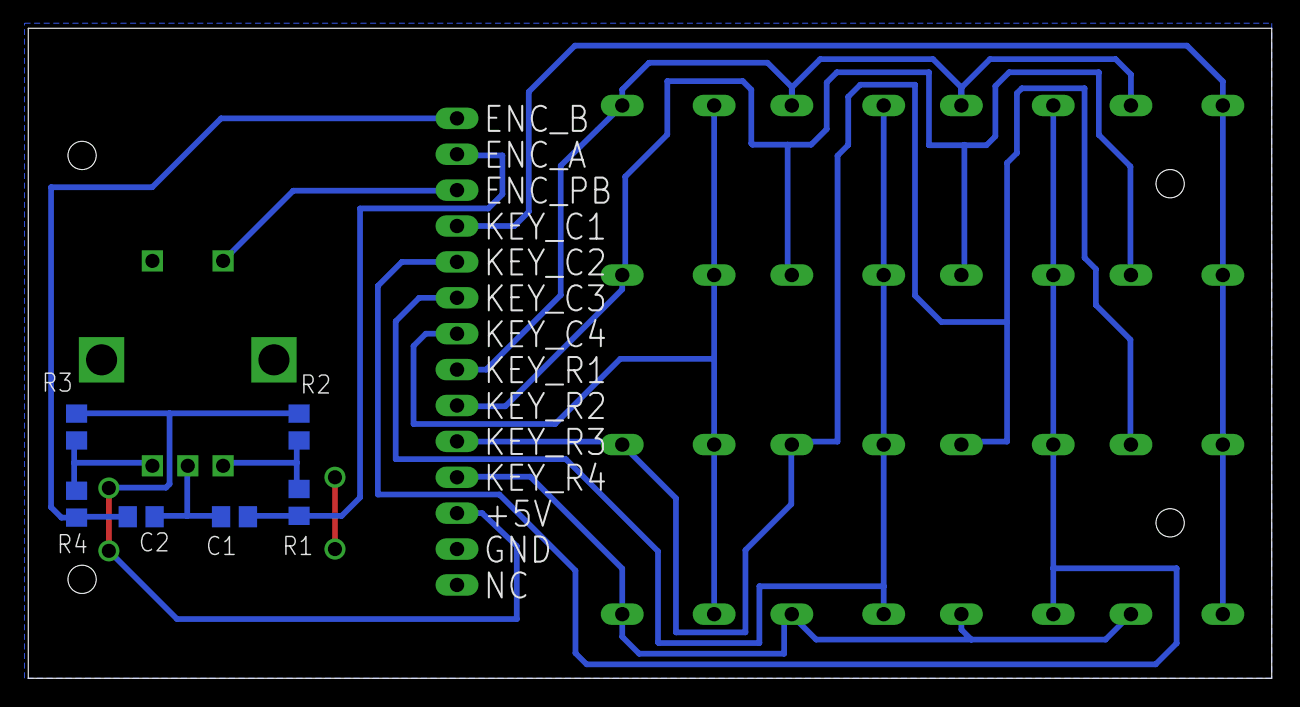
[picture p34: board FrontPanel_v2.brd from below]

Board: 2 copper layers, 88.0 x 46.0 mm, 24 parts (6 on the bottom side), 15 nets.

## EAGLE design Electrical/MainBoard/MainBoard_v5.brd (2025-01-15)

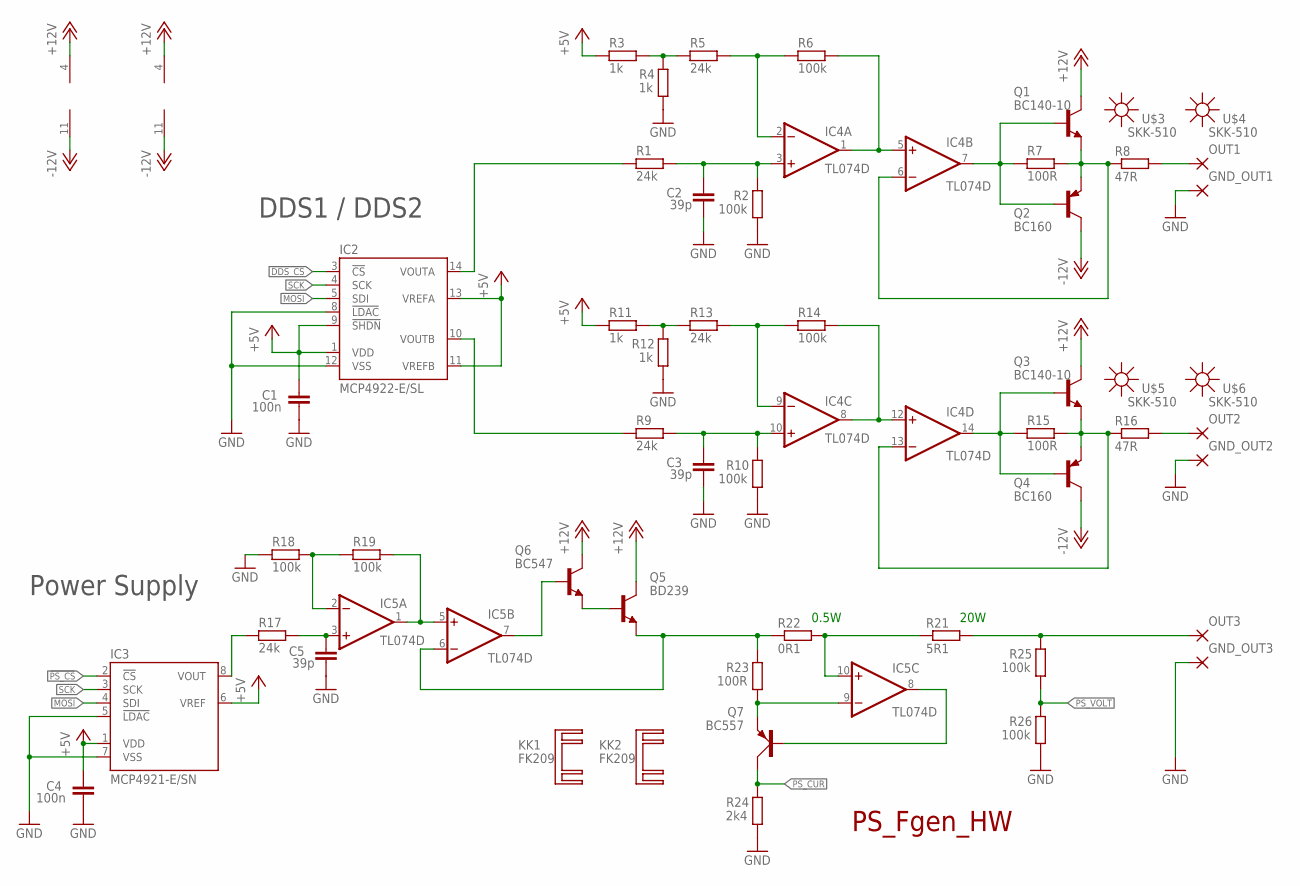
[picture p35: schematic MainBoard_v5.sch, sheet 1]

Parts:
C1, C4: 100n; C0805
C2, C3, C5: 39p; C0805
GND_OUT1, GND_OUT2, GND_OUT3: 2,54/1,0
IC2: MCP4922-E/SL; SO14
IC3: MCP4921-E/SN; SO08
IC4, IC5: TL074D; SO14
KK1, KK2: FK209
OUT1, OUT2, OUT3: 2,54/1,0
Q1, Q3: BC140-10; TO39
Q2, Q4: BC160; TO39
Q5: BD239; CB-274
Q6: BC547; TO92
Q7: BC557; SOT54A
R1, R5, R9, R13, R17: 24k; R0805
R2, R6, R10, R14, R18, R19, R25, R26: 100k; R0805
R3, R4, R11, R12: 1k; R0805
R7, R15, R23: 100R; R0805
R8, R16: 47R; 0411/15
R21: 5R1; 0411/15
R22: 0R1; 0411/15
R24: 2k4; R0805
U$3, U$4, U$5, U$6: SKK-510; SKK

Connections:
!DDS_CS: IC2.3 (!CS); also elsewhere on the board
!PS_CS: IC3.2 (!CS); also elsewhere on the board
+5V: C1.2, C4.2, IC2.1 (VDD), IC2.9 (!SHDN), IC2.11 (VREFB), IC2.13 (VREFA), IC3.1 (VDD), IC3.6 (VREF), R3.1, R11.1; also elsewhere on the board
+12V: IC4.4 (V+), IC5.4 (V+), Q1.3 (C), Q3.3 (C), Q5.T2 (C), Q6.3 (C); also elsewhere on the board
-12V: IC4.11 (V-), IC5.11 (V-), Q2.3 (C), Q4.3 (C); also elsewhere on the board
GND: C1.1, C2.1, C3.1, C4.1, C5.1, GND_OUT1.1, GND_OUT2.1, GND_OUT3.1, IC2.8 (!LDAC), IC2.12 (VSS), IC3.5 (!LDAC), IC3.7 (VSS), R2.1, R4.1, R10.1, R12.1, R18.1, R24.1, R26.1; also elsewhere on the board
MOSI: IC2.5 (SDI), IC3.4 (SDI); also elsewhere on the board
unnamed: IC2.14 (VOUTA), R1.1
unnamed: C2.2, IC4.3 (+IN), R1.2, R2.2
unnamed: R3.2, R4.2, R5.1
unnamed: IC4.2 (-IN), R5.2, R6.1
unnamed: IC4.7 (OUT), Q1.2 (B), Q2.2 (B), R7.1
unnamed: IC4.1 (OUT), IC4.5 (+IN), R6.2
unnamed: IC4.6 (-IN), Q1.1 (E), Q2.1 (E), R7.2, R8.1
unnamed: R11.2, R12.2, R13.1
unnamed: IC4.9 (-IN), R13.2, R14.1
unnamed: C3.2, IC4.10 (+IN), R9.2, R10.2
unnamed: IC4.8 (OUT), IC4.12 (+IN), R14.2
unnamed: IC2.10 (VOUTB), R9.1
unnamed: IC4.14 (OUT), Q3.2 (B), Q4.2 (B), R15.1
unnamed: IC4.13 (-IN), Q3.1 (E), Q4.1 (E), R15.2, R16.1
unnamed: IC3.8 (VOUT), R17.1
unnamed: C5.2, IC5.3 (+IN), R17.2
unnamed: IC5.2 (-IN), R18.2, R19.1
unnamed: IC5.6 (-IN), Q5.G (E), R22.1, R23.2
unnamed: IC5.1 (OUT), IC5.5 (+IN), R19.2
unnamed: Q5.T1 (B), Q6.1 (E)
unnamed: OUT3.1, R21.2, R25.2
unnamed: IC5.9 (-IN), Q7.E, R23.1
unnamed: IC5.8 (OUT), Q7.B
unnamed: OUT2.1, R16.2
unnamed: OUT1.1, R8.2
unnamed: IC5.7 (OUT), Q6.2 (B)
unnamed: IC5.10 (+IN), R21.1, R22.2
PS_CUR: Q7.C, R24.2; also elsewhere on the board
PS_VOLT: R25.1, R26.2; also elsewhere on the board
SCK: IC2.4 (SCK), IC3.3 (SCK); also elsewhere on the board

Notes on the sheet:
PS_Fgen_HW
DDS1 / DDS2
Power Supply
0.5W
20W

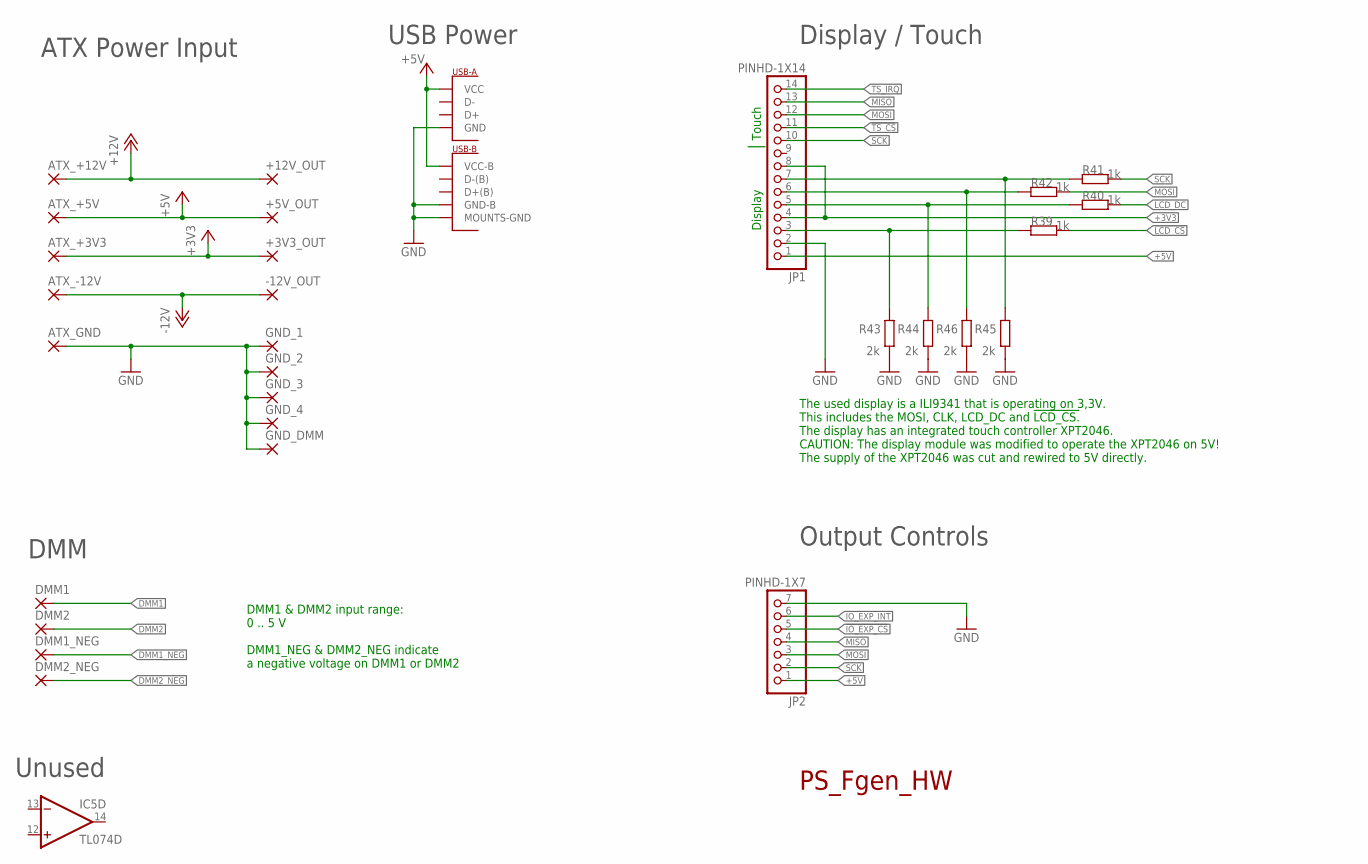
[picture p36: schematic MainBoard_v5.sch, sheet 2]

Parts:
+3V3_OUT, +5V_OUT, +12V_OUT: 2,54/1,0
-12V_OUT: 2,54/1,0
ATX_+3V3, ATX_+5V, ATX_+12V: 2,54/1,0
ATX_-12V: 2,54/1,0
ATX_GND: 2,54/1,0
DMM1, DMM1_NEG, DMM2, DMM2_NEG: 2,54/1,0
GND_1, GND_2, GND_3, GND_4: 2,54/1,0
GND_DMM: 2,54/1,0
IC5: TL074D; SO14
JP1: PINHD-1X14; 1X14
JP2: PINHD-1X7; 1X07
R39, R40, R41, R42: 1k; R0805
R43, R44, R45, R46: 2k; R0805
U$2: DUAL-PORT-USB-REC; DUAL-PORT-USB

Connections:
!IO_EXP_CS: JP2.5; also elsewhere on the board
!LCD_CS: R39.2; also elsewhere on the board
!LCD_CS_3V3: JP1.3, R39.1, R43.1
!TS_CS: JP1.11; also elsewhere on the board
+3V3: +3V3_OUT.1, ATX_+3V3.1, JP1.4, JP1.8; also elsewhere on the board
+5V: +5V_OUT.1, ATX_+5V.1, JP1.1, JP2.1, U$2.P$10 (VCC-B), U$2.P$12 (VCC); also elsewhere on the board
+12V: +12V_OUT.1, ATX_+12V.1; also elsewhere on the board
-12V: -12V_OUT.1, ATX_-12V.1; also elsewhere on the board
DMM1: DMM1.1; also elsewhere on the board
DMM1_NEG: DMM1_NEG.1; also elsewhere on the board
DMM2: DMM2.1; also elsewhere on the board
DMM2_NEG: DMM2_NEG.1; also elsewhere on the board
GND: ATX_GND.1, GND_1.1, GND_2.1, GND_3.1, GND_4.1, GND_DMM.1, JP1.2, JP2.7, R43.2, R44.2, R45.2, R46.2, U$2.GND (MOUNTS-GND), U$2.P$2 (MOUNTS-GND), U$2.P$3 (MOUNTS-GND), U$2.P$4 (MOUNTS-GND), U$2.P$9 (GND-B), U$2.P$11 (GND); also elsewhere on the board
IO_EXP_INT: JP2.6; also elsewhere on the board
LCD_DC: R40.2; also elsewhere on the board
MISO: JP1.13, JP2.4; also elsewhere on the board
MOSI: JP1.12, JP2.3, R42.2; also elsewhere on the board
MOSI_3V3: JP1.6, R42.1, R46.1
unnamed: JP1.5, R40.1, R44.1
SCK: JP1.10, JP2.2, R41.2; also elsewhere on the board
SCK_3V3: JP1.7, R41.1, R45.1
TS_IRQ: JP1.14; also elsewhere on the board

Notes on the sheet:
PS_Fgen_HW
Display / Touch
Unused
DMM
USB Power
ATX Power Input
DMM1 & DMM2 input range: 0 .. 5 V DMM1_NEG & DMM2_NEG indicate a negative voltage on DMM1 or DMM2
The used display is a ILI9341 that is operating on 3,3V. This includes the MOSI, CLK, LCD_DC and !LCD_CS. The display has an integrated touch controller XPT2046. CAUTION: The display module was modified to operate the XPT2046 on 5V! The supply of the XPT2046 was cut and rewired to 5V directly.
Display
Touch
Output Controls

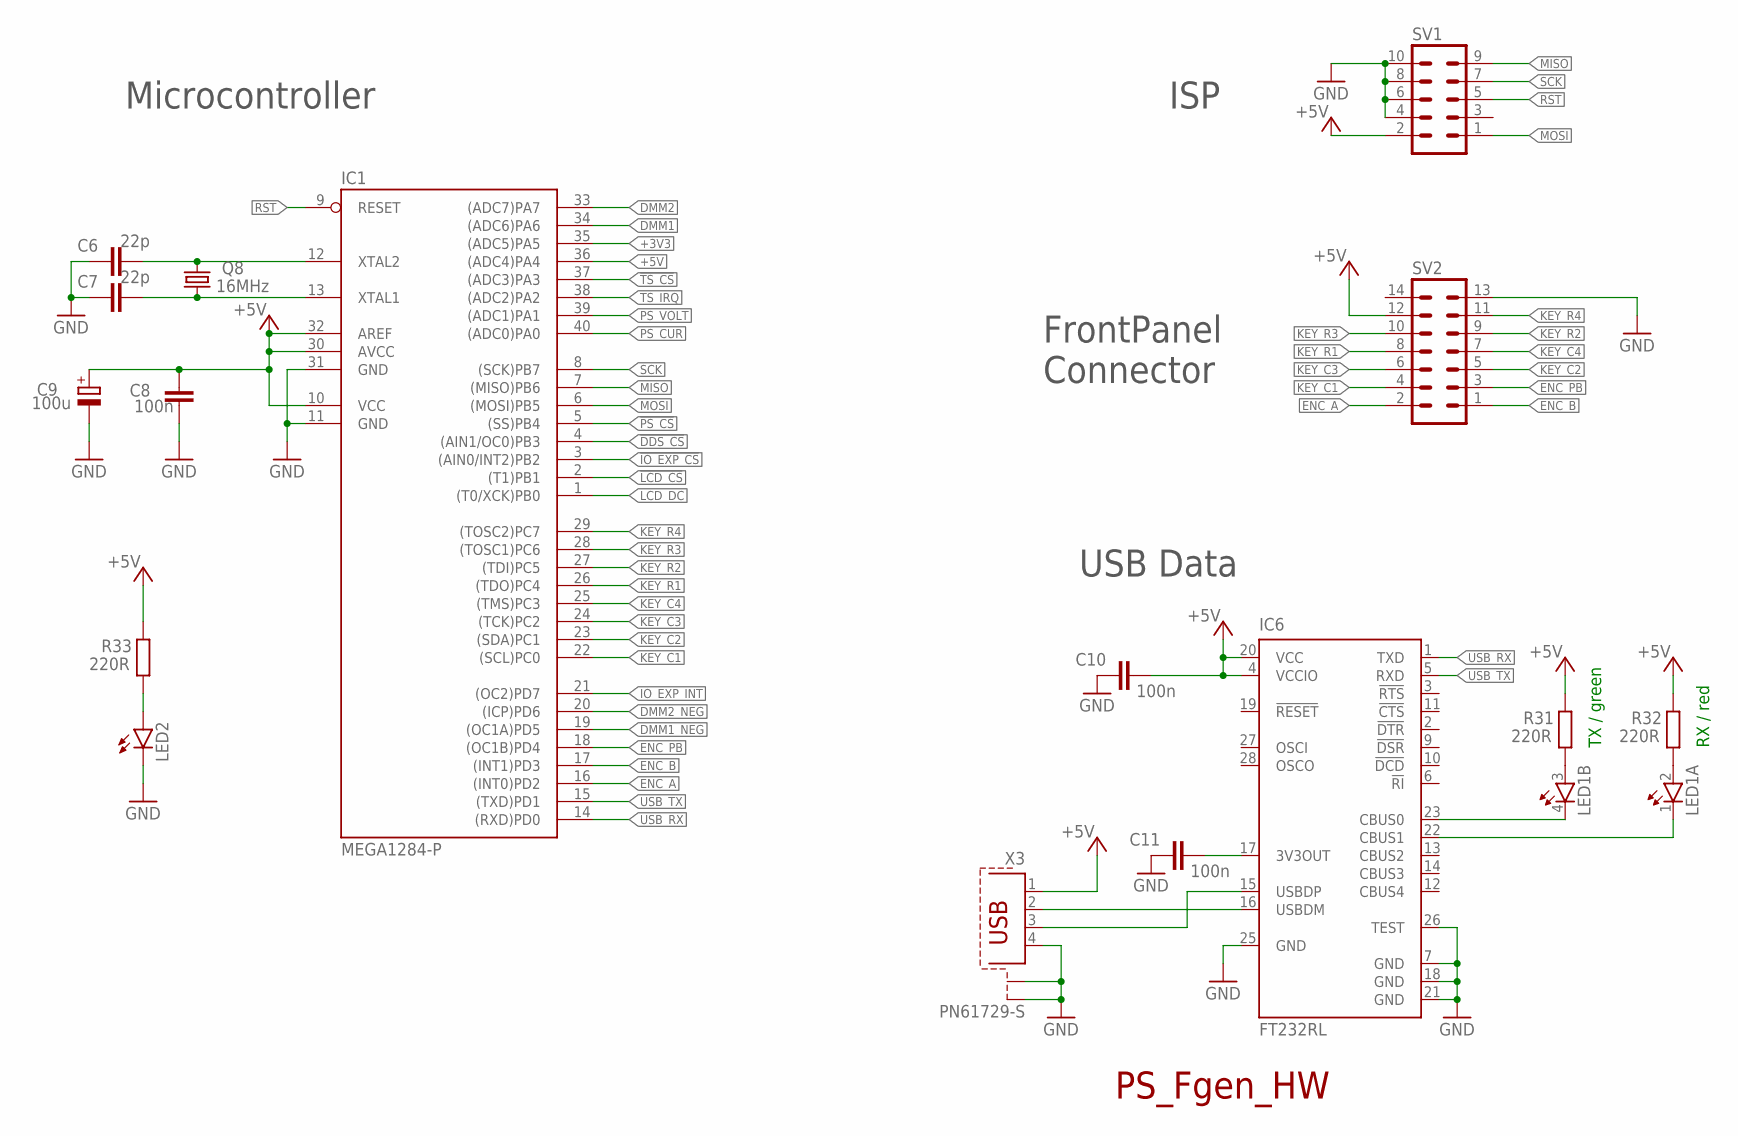
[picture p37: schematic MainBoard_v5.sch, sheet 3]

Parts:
C6, C7: 22p; C0805
C8, C10, C11: 100n; C0805
C9: 100u; PANASONIC_D
IC1: MEGA1284-P; DIL40
IC6: FT232RL; SSOP28
LED1: TOPLED-2--; P-LCC-4-2
LED2: LEDCHIP-LED0805; CHIP-LED0805
Q8: 16MHz; HC49/S
R31, R32, R33: 220R; R0805
SV1: ML10
SV2: ML14
X3: PN61729-S

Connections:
!DDS_CS: IC1.4 ((AIN1/OC0)PB3); also elsewhere on the board
!IO_EXP_CS: IC1.3 ((AIN0/INT2)PB2); also elsewhere on the board
!LCD_CS: IC1.2 ((T1)PB1); also elsewhere on the board
!PS_CS: IC1.5 ((SS)PB4); also elsewhere on the board
!TS_CS: IC1.37 ((ADC3)PA3); also elsewhere on the board
+3V3: IC1.35 ((ADC5)PA5); also elsewhere on the board
+5V: C8.2, C9.+, C10.1, IC1.10 (VCC), IC1.30 (AVCC), IC1.32 (AREF), IC1.36 ((ADC4)PA4), IC6.4 (VCCIO), IC6.20 (VCC), R31.2, R32.2, R33.2, SV1.2, SV2.12, X3.1; also elsewhere on the board
DMM1: IC1.34 ((ADC6)PA6); also elsewhere on the board
DMM1_NEG: IC1.19 ((OC1A)PD5); also elsewhere on the board
DMM2: IC1.33 ((ADC7)PA7); also elsewhere on the board
DMM2_NEG: IC1.20 ((ICP)PD6); also elsewhere on the board
ENC_A: IC1.16 ((INT0)PD2), SV2.2
ENC_B: IC1.17 ((INT1)PD3), SV2.1
ENC_PB: IC1.18 ((OC1B)PD4), SV2.3
GND: C6.2, C7.2, C8.1, C9.-, C10.2, C11.2, IC1.11 (GND), IC1.31 (GND), IC6.7 (GND), IC6.18 (GND), IC6.21 (GND), IC6.25 (GND), IC6.26 (TEST), LED2.C, SV1.4, SV1.6, SV1.8, SV1.10, SV2.13, X3.4, X3.S1, X3.S2; also elsewhere on the board
IO_EXP_INT: IC1.21 ((OC2)PD7); also elsewhere on the board
KEY_C1: IC1.22 ((SCL)PC0), SV2.4
KEY_C2: IC1.23 ((SDA)PC1), SV2.5
KEY_C3: IC1.24 ((TCK)PC2), SV2.6
KEY_C4: IC1.25 ((TMS)PC3), SV2.7
KEY_R1: IC1.26 ((TDO)PC4), SV2.8
KEY_R2: IC1.27 ((TDI)PC5), SV2.9
KEY_R3: IC1.28 ((TOSC1)PC6), SV2.10
KEY_R4: IC1.29 ((TOSC2)PC7), SV2.11
LCD_DC: IC1.1 ((T0/XCK)PB0); also elsewhere on the board
MISO: IC1.7 ((MISO)PB6), SV1.9; also elsewhere on the board
MOSI: IC1.6 ((MOSI)PB5), SV1.1; also elsewhere on the board
unnamed: C7.1, IC1.13 (XTAL1), Q8.1
unnamed: C6.1, IC1.12 (XTAL2), Q8.2
unnamed: C11.1, IC6.17 (3V3OUT)
unnamed: IC6.16 (USBDM), X3.2
unnamed: IC6.15 (USBDP), X3.3
unnamed: IC6.23 (CBUS0), LED1.4 (C)
unnamed: IC6.22 (CBUS1), LED1.1 (C)
unnamed: LED1.3 (A), R31.1
unnamed: LED1.2 (A), R32.1
unnamed: LED2.A, R33.1
PS_CUR: IC1.40 ((ADC0)PA0); also elsewhere on the board
PS_VOLT: IC1.39 ((ADC1)PA1); also elsewhere on the board
RST: IC1.9 (RESET), SV1.5
SCK: IC1.8 ((SCK)PB7), SV1.7; also elsewhere on the board
TS_IRQ: IC1.38 ((ADC2)PA2); also elsewhere on the board
USB_RX: IC1.14 ((RXD)PD0), IC6.1 (TXD)
USB_TX: IC1.15 ((TXD)PD1), IC6.5 (RXD)

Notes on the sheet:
TX / green
RX / red
PS_Fgen_HW
Microcontroller
ISP
FrontPanel Connector
USB Data

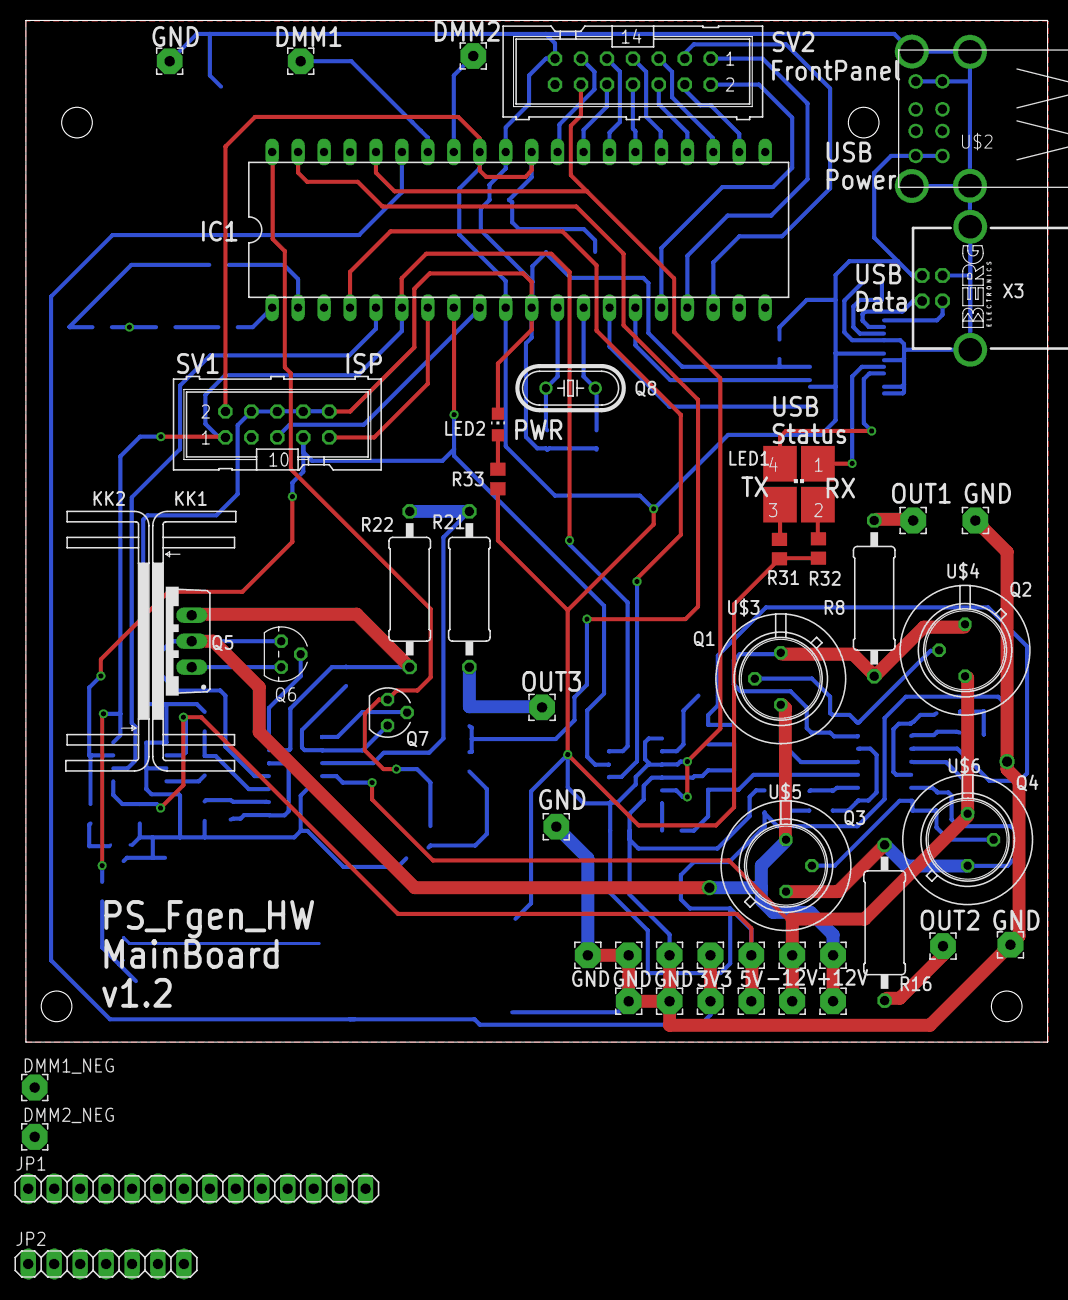
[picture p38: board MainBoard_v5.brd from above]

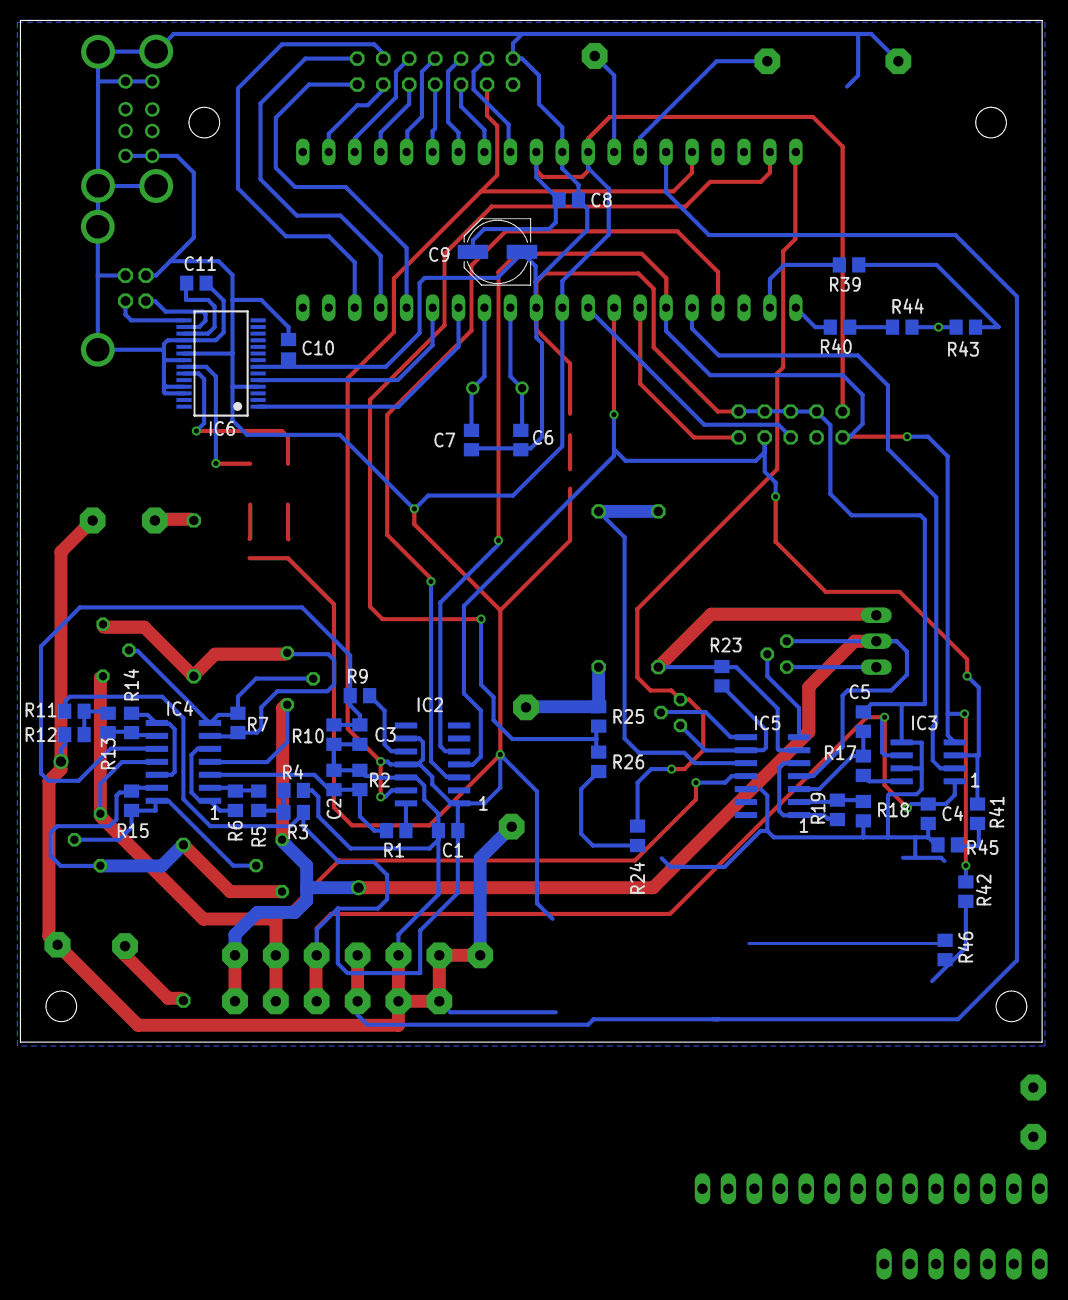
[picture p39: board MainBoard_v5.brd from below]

Board: 2 copper layers, 100.0 x 100.0 mm, 99 parts (45 on the bottom side), 77 nets.

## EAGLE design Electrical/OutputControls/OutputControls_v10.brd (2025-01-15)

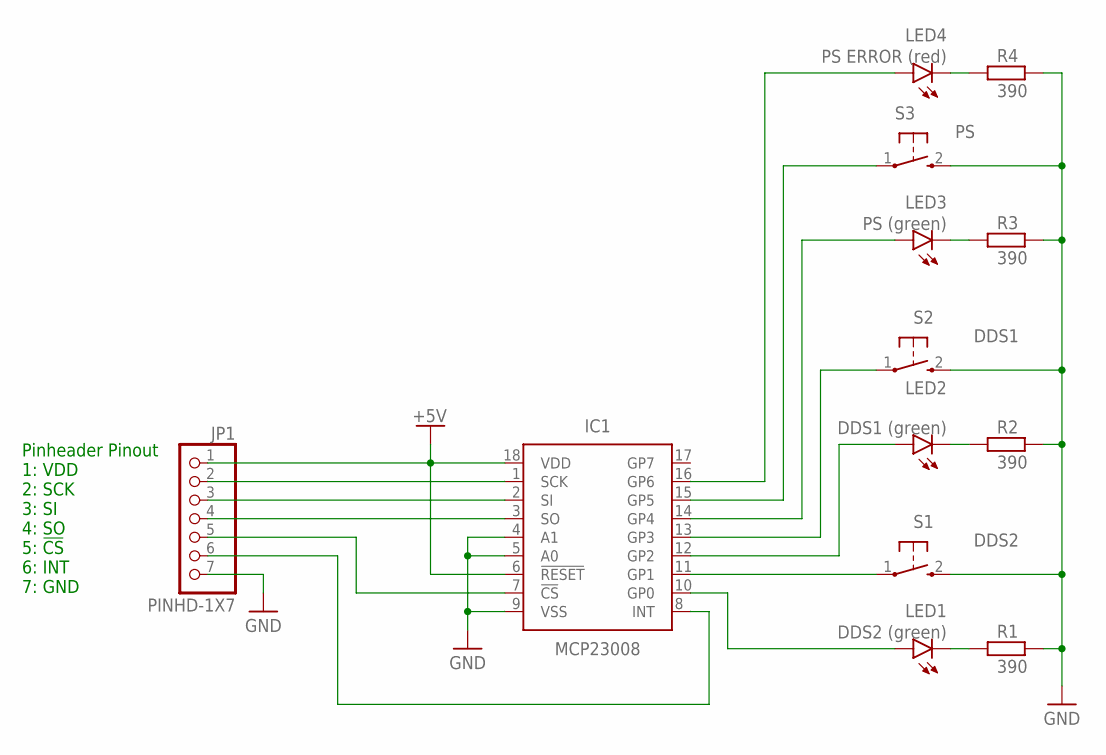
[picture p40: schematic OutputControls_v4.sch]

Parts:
IC1: MCP23008; SOIC127P1030X265-18N
JP1: PINHD-1X7; 1X07
LED1: DDS2 (green); CHIPLED_0603
LED2: DDS1 (green); CHIPLED_0603
LED3: PS (green); CHIPLED_0603
LED4: PS ERROR (red); CHIPLED_0603
R1, R2, R3, R4: 390; R0805
S1: DDS2; B3F-10XX
S2: DDS1; B3F-10XX
S3: PS; B3F-10XX

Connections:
+5V: IC1.6 (!RESET), IC1.18 (VDD), JP1.1
GND: IC1.4 (A1), IC1.5 (A0), IC1.9 (VSS), JP1.7, R1.2, R2.2, R3.2, R4.2, S1.2 (S), S2.2 (S), S3.2 (S)
unnamed: IC1.10 (GP0), LED1.A
unnamed: IC1.11 (GP1), S1.1
unnamed: IC1.12 (GP2), LED2.A
unnamed: LED1.C, R1.1
unnamed: LED2.C, R2.1
unnamed: LED3.C, R3.1
unnamed: IC1.13 (GP3), S2.1
unnamed: IC1.14 (GP4), LED3.A
unnamed: IC1.15 (GP5), S3.1
unnamed: LED4.C, R4.1
unnamed: IC1.1 (SCK), JP1.2
unnamed: IC1.2 (SI), JP1.3
unnamed: IC1.3 (SO), JP1.4
unnamed: IC1.7 (!CS), JP1.5
unnamed: IC1.8 (INT), JP1.6
unnamed: IC1.16 (GP6), LED4.A

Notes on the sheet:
Pinheader Pinout 1: VDD 2: SCK 3: SI 4: SO 5: !CS 6: INT 7: GND

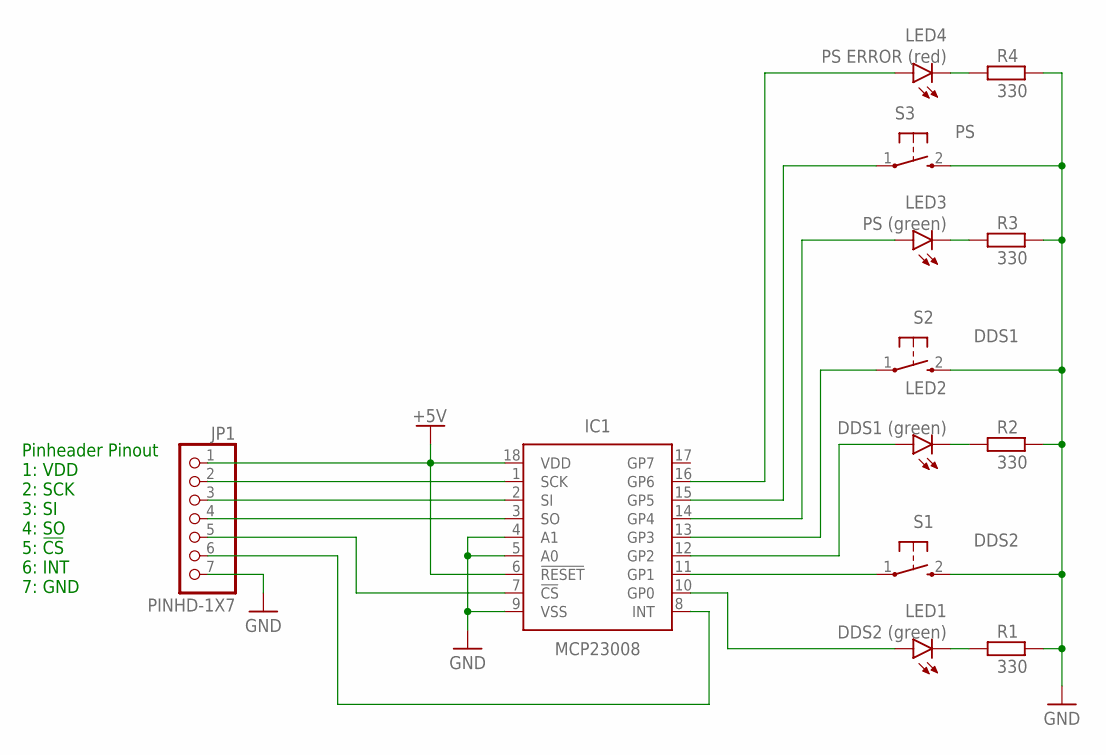
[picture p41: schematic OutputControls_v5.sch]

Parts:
IC1: MCP23008; SOIC127P1030X265-18N
JP1: PINHD-1X7; 1X07
LED1: DDS2 (green); CHIPLED_0603
LED2: DDS1 (green); CHIPLED_0603
LED3: PS (green); CHIPLED_0603
LED4: PS ERROR (red); CHIPLED_0603
R1, R2, R3, R4: 330; R0805
S1: DDS2; B3F-10XX
S2: DDS1; B3F-10XX
S3: PS; B3F-10XX

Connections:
+5V: IC1.6 (!RESET), IC1.18 (VDD), JP1.1
GND: IC1.4 (A1), IC1.5 (A0), IC1.9 (VSS), JP1.7, R1.2, R2.2, R3.2, R4.2, S1.2 (S), S2.2 (S), S3.2 (S)
unnamed: IC1.10 (GP0), LED1.A
unnamed: IC1.11 (GP1), S1.1
unnamed: IC1.12 (GP2), LED2.A
unnamed: LED1.C, R1.1
unnamed: LED2.C, R2.1
unnamed: LED3.C, R3.1
unnamed: IC1.13 (GP3), S2.1
unnamed: IC1.14 (GP4), LED3.A
unnamed: IC1.15 (GP5), S3.1
unnamed: LED4.C, R4.1
unnamed: IC1.1 (SCK), JP1.2
unnamed: IC1.2 (SI), JP1.3
unnamed: IC1.3 (SO), JP1.4
unnamed: IC1.7 (!CS), JP1.5
unnamed: IC1.8 (INT), JP1.6
unnamed: IC1.16 (GP6), LED4.A

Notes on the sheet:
Pinheader Pinout 1: VDD 2: SCK 3: SI 4: SO 5: !CS 6: INT 7: GND


Board: 2 copper layers, 40.0 x 40.0 mm, 13 parts (1 on the bottom side), 18 nets.

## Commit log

2021-06-01 Initial version under version control
    [Abdeckung_hinten.stl, Encoder_Knopf.stl, FrontPanel.brd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]
2021-06-01 Board resized
    [MainBoard.brd, MainBoard.csv, MainBoard.sch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]
2021-06-01 Resistors add to MainBoard to convert 5V to 3.3V for LCD signals
    [MainBoard.brd, MainBoard.csv, MainBoard.sch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]
2021-06-03 Updated to new project name (PS_Fgen_HW), removed Z-Diode and ATX_PWR_ON signal from MainBoard
    [FrontPanel.brd, FrontPanel.sch, MainBoard.brd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]
2021-06-03 MainBoard: Removed ATX_5V_SB input (combined VCC and +5V nets)
    [MainBoard.brd, MainBoard.csv, MainBoard.sch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]
2021-06-03 Mechanical components exported as single .f3d files
    [Abdeckung_hinten.f3d, Encoder_Knopf.f3d, FrontPanel_Rahmen.f3d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]
2021-07-05 Replaced Taste_komma by Taste_x1
    [Taste_komma.f3d, Taste_komma.stl, Taste_x1.f3d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]
2021-07-14 Added Schublade to housing to store cables etc.
    [Schrift_Seitenteil_links.f3d, Schrift_Seitenteil_links.stl, Seitenteil_links.f3d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]
2021-08-14 Removed some Z-Diodes, removed Resistor R20 (PowerSupply, between OpAmp IC5B and transistors Q5 and Q6)
    [MainBoard.brd, MainBoard.sch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]
2021-08-29 Changed Resistor values of PowerSupply current measurement circuit (R21, R22, R23)
    [MainBoard.brd, MainBoard.csv, MainBoard.sch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]
2021-09-02 Changed power stage of PowerSupply channel
    [MainBoard.brd, MainBoard.sch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]
2021-09-08 Removed Z-Diode D1 (PS_CUR), moved resistor R21 of current measurement circuit to be after this circuit
    [MainBoard.brd, MainBoard.sch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]
2021-12-01 Added cover for Schublade to housing
    [Seitenteil_links.f3d, Seitenteil_links.stl]
2022-01-05 Added Standfuss models
    [Standfuss.f3d, Standfuss.stl]
2022-04-26 Added DMMRectifier to Electrical folder
    [DMMRectifier.brd, DMMRectifier.sch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]
2022-04-28 Modified DMM circuit to use DMMRectifier PCB
    [MainBoard.brd, MainBoard.sch, Seitenteil_rechts.f3d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]
2022-05-03 Adapted pilars of Seitenteil_rechts for DMMRectifier LEDs
    [Seitenteil_rechts.f3d, Seitenteil_rechts.stl]
2024-09-03 Added OutputControls to Electrical folder
    [OutputControls_v4.sch, OutputControls_v9.brd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]
2025-01-15 Updated OutputControls and MainBoard in Electrical folder
    [MainBoard_v5.brd, MainBoard_v5.sch, OutputControls_v10.brd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]
2025-01-15 Updated FrontPanel and DMMRectifier in Electrical folder
    [DMMRectifier_v2.brd, DMMRectifier_v2.sch, FrontPanel_v2.brd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]
2025-01-18 Updated all parts in Mechanical folder
    [Abdeckung_hinten.f3d, Abdeckung_hinten.stl, Abdeckung_hinten_v56.f3d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]
